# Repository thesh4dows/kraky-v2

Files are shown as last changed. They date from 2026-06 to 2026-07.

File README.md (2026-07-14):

# kraky-v2
Kraky2 is the second version of the DIY and open-hardware poject inspired by the Flipper Zero.
It uses the esp32-S3 microntroller to manage all the different modules like the NFC,RFID, and some.

The module is divided in 2 layers, the front one houses the esp32, Wifi and Sub-GHz antennas, buttons, IR and a part of the
power delivery system; the back one houses the NFC and RFID modules on top of the rest of the power delivery system.

Using the four buttons you can take advantage of all the modules that composes the kraky2, you can also use it connected to 
a battery or via the usb-c port that is integrated in the circuit.

I would suggest putting first the esp32 as is the most difficult part to put, then the others chip, all the capacitors, resistors, inductors and so on and for last all the
tht components because they are the ones that pass through the board so they are more simple to put.

I started this journey because i want to create a better version of my project kraky, and i'm doing it by first using smd components instead of the 
tht modules so i can do some expirience soldering very small parts and stopping using pre made modules but recreating them myself.
420.65
---

# Main Components
| Function | Component |
|---|---|
| Logic board | **ESP32-S3 N16R8** |
| wifi | **nrf24l01** |
| Sub-GHz | **CC1101** |
| RFID | **MFRC522** |
| NFC | **PN532** |
| Battery charger | **CN3163** |
| Battery | Li-ion |
| IR Receiver | **TSOP38238** |
| IR Transmitter | IR LED |
| microSD Slot | **MSD4A** |
| Buttons | 4 tactile buttons |
| Display | TFT Display |

---

# WIRING DIAGRAM

# ESP32



 # POWER DELIVERY SYSTEM
 


# IR



# WIFI



# SUB-GHZ



# MICROSD SLOT



# NFC



# RFID



# BUTTONS



# DISPLAY



---

# PCB



---

# 3D RENDER





---
# Responsible Use
Kraky2 is built to make it easier for anyone to explore and understand how multifunction electronic devices work in everyday life. It’s not intended for bypassing security systems or breaking any laws.

All features are implemented with an educational and experimental focus.

---

# Zine page

kraky2 poster (5)

---

# Tools Used

- KiCad 10
- Fusion360
- PlatformIO
---
## Contributing

Kraky is an **open and educational project**.  
Feedback, suggestions, and improvements are always welcome.

---

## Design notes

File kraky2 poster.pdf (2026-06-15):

# KRAKY2

## SUB-GHZ

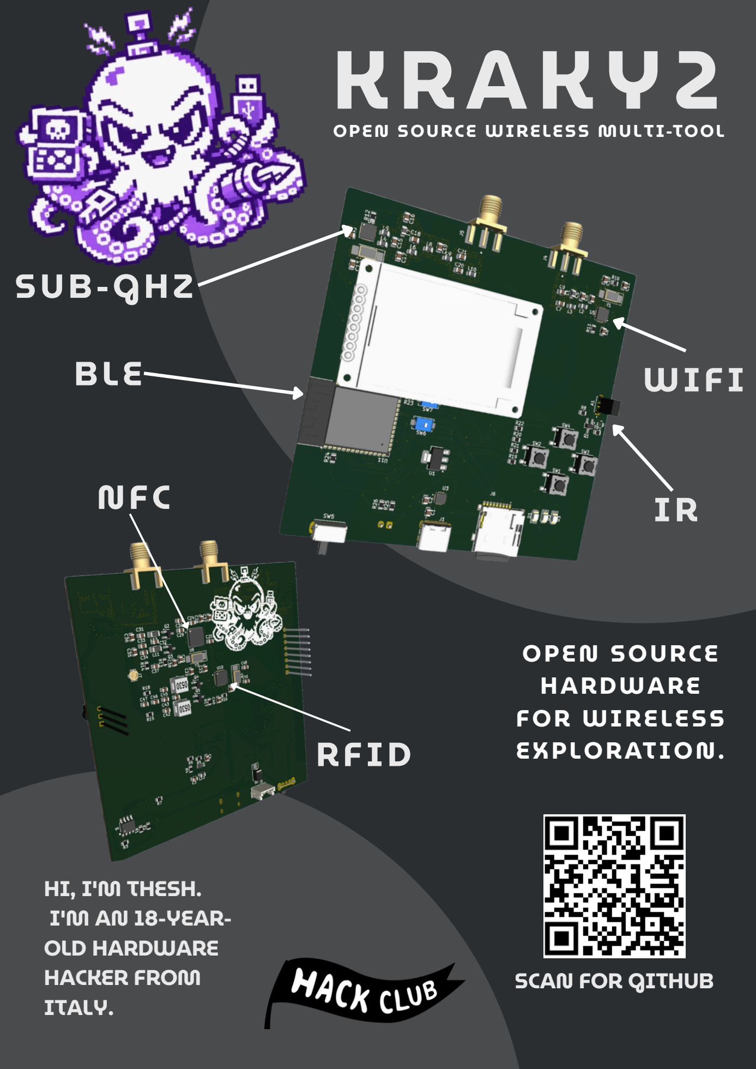
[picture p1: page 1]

HI, I'M THESH.
I'M AN 18-YEAR-OLD HARDWARE
HACKER FROM
ITALY.

SCAN FOR GITHUB

## NFC

## RFID

## WIFI

IR

## BLE

OPEN SOURCE WIRELESS MULTI-TOOL

OPEN SOURCE
HARDWARE
FOR WIRELESS
EXPLORATION.

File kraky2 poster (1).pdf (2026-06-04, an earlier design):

# KRAKY2

## SUB-GHZ

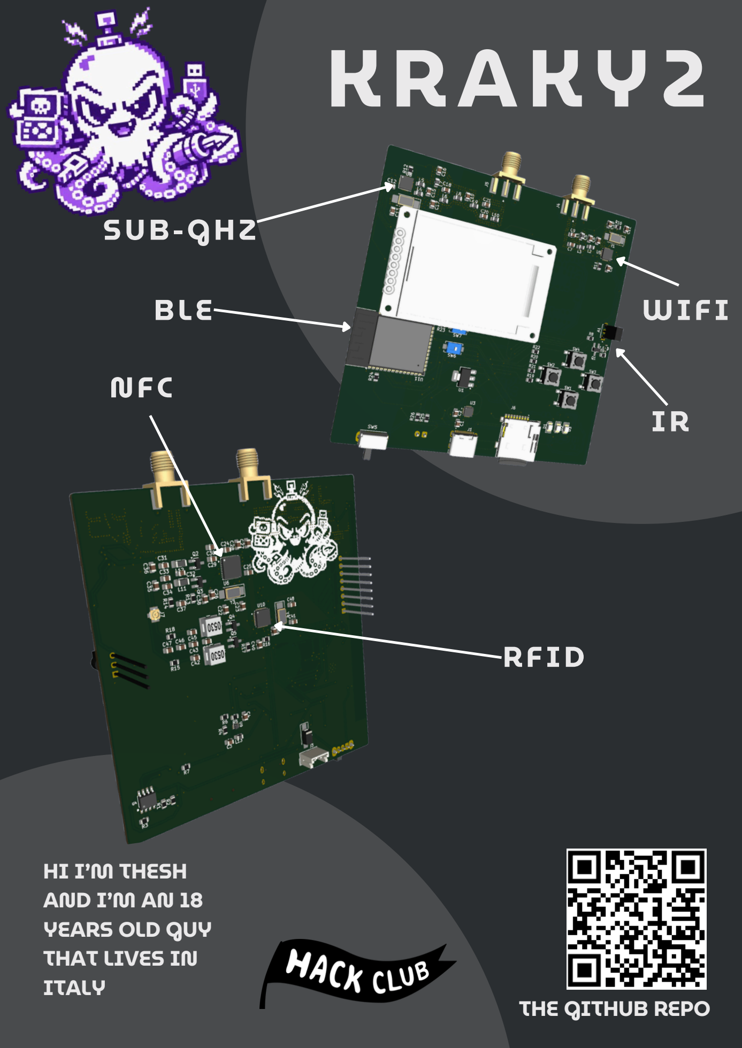
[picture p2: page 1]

HI I’M THESH
AND I’M AN 18
YEARS OLD GUY
THAT LIVES IN
ITALY
THE GITHUB REPO

## NFC

## RFID

## WIFI

IR

## BLE

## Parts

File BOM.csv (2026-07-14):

name | value | link | description | cost | quantity | added
resistor
R1 | 220 | https://it.aliexpress.com/item/1005010070793079.html?curPageLogUid=H7QIyXNC0fT4 | 805 | 1.45 | 3
R2 | 220 | R1 | 805 | R1 | R1
R3 | 3.6K | https://it.aliexpress.com/item/1005010070793079.html?curPageLogUid=H7QIyXNC0fT4 | 805 | 1.45 | 1
R4 | 100 | https://it.aliexpress.com/item/1005010070793079.html?curPageLogUid=H7QIyXNC0fT4 | 805 | 1.45 | 2
R5 | 732K | https://it.aliexpress.com/item/1005005184230104.html?curPageLogUid=FjpJxLWFyGgd | 805 | 2.07 | 1
R6 | 100K | https://it.aliexpress.com/item/1005010070793079.html?curPageLogUid=H7QIyXNC0fT4 | 805 | 1.45 | 3
R7 | 220 | R1 | 805 | R1 | R1
R8 | 1K | https://it.aliexpress.com/item/1005010070793079.html?curPageLogUid=H7QIyXNC0fT4 | 805 | 1.45 | 6
R9 | 100 | R4 | 805 | R4 | R4
R10 | 1M | https://it.aliexpress.com/item/1005010070793079.html?curPageLogUid=H7QIyXNC0fT4 | 805 | 1.46 | 1
R11 | 22K | https://it.aliexpress.com/item/1005010070793079.html?curPageLogUid=H7QIyXNC0fT4 | 805 | 1.45 | 1
R12 | 56K | https://it.aliexpress.com/item/1005010070793079.html?curPageLogUid=H7QIyXNC0fT4 | 805 | 1.45 | 1
R13 | 1K | R8 | 805 | R8 | R8
R14 | 1.6K | https://it.aliexpress.com/item/1005010070793079.html?curPageLogUid=H7QIyXNC0fT4 | 805 | 1.45 | 1
R15 | 1K | R8 | 805 | R8 | R8
R16 | 1K | R8 | 805 | R8 | R8
R17 | 1K | R8 | 805 | R8 | R8
R18 | 1K | R8 | 805 | R8 | R8
R19 | 10K | https://it.aliexpress.com/item/1005010070793079.html?curPageLogUid=H7QIyXNC0fT4 | 805 | 1.45 | 6
R20 | 10K | R19 | 805 | R19 | R19
R21 | 10K | R19 | 805 | R19 | R19
R22 | 10K | R19 | 805 | R19 | R19
R23 | 10K | R19 | 805 | R19 | R19
R24 | 10K | R19 | 805 | R19 | R19
R25 | 100K | R6 | 805 | R6 | R6
R26 | 100K | R6 | 805 | R6 | R6
capacitor
C1 | 0.1 uF | https://it.aliexpress.com/item/1005005929029743.html?curPageLogUid=6vnH26Bvr1Cc | 805 | 1.22 | 7
C2 | 1 uF | https://it.aliexpress.com/item/1005005929029743.html?curPageLogUid=6vnH26Bvr1Cc | 805 | 1.6 | 11
C3 | 10 uF | https://it.aliexpress.com/item/1005005929029743.html?curPageLogUid=6vnH26Bvr1Cc | 805 | 1.46 | 2
C4 | 22 uF | https://it.aliexpress.com/item/1005005929029743.html?curPageLogUid=6vnH26Bvr1Cc | 805 | 1.6 | 1
C5 | 2.2 nF | https://it.aliexpress.com/item/1005005929029743.html?curPageLogUid=6vnH26Bvr1Cc | 805 | 1.36 | 1
C6 | 4.7 pF | https://it.aliexpress.com/item/1005005929029743.html?curPageLogUid=6vnH26Bvr1Cc | 805 | 1.36 | 1
C7 | 1.5 pF | https://it.aliexpress.com/item/1005005929029743.html?curPageLogUid=6vnH26Bvr1Cc | 805 | 1.36 | 3
C8 | 33 nF | https://it.aliexpress.com/item/1005005929029743.html?curPageLogUid=6vnH26Bvr1Cc | 805 | 1.37 | 1
C9 | 1 pF | https://it.aliexpress.com/item/1005005929029743.html?curPageLogUid=6vnH26Bvr1Cc | 805 | 1.36 | 2
C10 | 22 pF | https://it.aliexpress.com/item/1005005929029743.html?curPageLogUid=6vnH26Bvr1Cc | 805 | 1.38 | 6
C11 | 22 pF | C10 | 805 | C10 | C10
C12 | 100 nF | https://it.aliexpress.com/item/1005005929029743.html?curPageLogUid=6vnH26Bvr1Cc | 805 | 1.21 | 1
C13 | 27 pF | https://it.aliexpress.com/item/1005005929029743.html?curPageLogUid=6vnH26Bvr1Cc | 805 | 1.38 | 2
C14 | 27 pF | C13 | 805 | C13 | C13
C15 | 1 pF | C9 | 805 | C9 | C9
C16 | 100 pF | https://it.aliexpress.com/item/1005005929029743.html?curPageLogUid=6vnH26Bvr1Cc | 805 | 1.36 | 1
C17 | 1.5 pF | C7 | 805 | C7 | C7
C18 | 1.5pF | C7 | 805 | C7 | C7
C19 | 3.3 pF | https://it.aliexpress.com/item/1005005929029743.html?curPageLogUid=6vnH26Bvr1Cc | 805 | 1.38 | 1
C20 | 47 pF | https://it.aliexpress.com/item/1005005929029743.html?curPageLogUid=6vnH26Bvr1Cc | 805 | 1.38 | 1
C21 | 12 pF | https://it.aliexpress.com/item/1005005929029743.html?curPageLogUid=6vnH26Bvr1Cc | 805 | 1.38 | 1
C22 | 22 pF | C10 | 805 | C10 | C10
C23 | 22 pF | C10 | 805 | C10 | C10
C24 | 0.1 uF | C1 | 805 | C1 | C1
C25 | 0.1 uF | C1 | 805 | C1 | C1
C26 | 0.1 uF | C1 | 805 | C1 | C1
C27 | 0.1 uF | C1 | 805 | C1 | C1
C28 | 10 uF | C3 | 805 | C3 | C3
C29 | 0.1 uF | C1 | 805 | C1 | C1
C30 | 4.7 uF | https://it.aliexpress.com/item/1005005929029743.html?curPageLogUid=6vnH26Bvr1Cc | 805 | 1.6 | 1
C31 | 22 pF | C10 | 805 | C10 | C10
C32 | 220 pF | https://it.aliexpress.com/item/1005005929029743.html?curPageLogUid=6vnH26Bvr1Cc | 805 | 1.38 | 2
C33 | 220 pF | C32 | 805 | C32 | C32
C34 | 22 pF | C10 | 805 | C10 | C10
C35 | 200 pF | https://it.aliexpress.com/item/1005005929029743.html?curPageLogUid=6vnH26Bvr1Cc | 805 | 1.38 | 2
C36 | 200 pF | C35 | 805 | C35 | C35
C37 | 1 nF | https://it.aliexpress.com/item/1005005929029743.html?curPageLogUid=6vnH26Bvr1Cc | 805 | 1.37 | 1
C38 | 0.1 uF | C1 | 805 | C1 | C1
C39 | 1 uF | C2 | 805 | C2 | C2
C40 | 1 uF | C2 | 805 | C2 | C2
C41 | 1 uF | C2 | 805 | C2 | C2
C42 | 1 uF | C2 | 805 | C2 | C2
C43 | 1 uF | C2 | 805 | C2 | C2
C44 | 1 uF | C2 | 805 | C2 | C2
C45 | 1 uF | C2 | 805 | C2 | C2
C46 | 1 uF | C2 | 805 | C2 | C2
C47 | 1 uF | C2 | 805 | C2 | C2
C48 | 1 uF | C2 | 805 | C2 | C2
inductor
L1 | 2.7 nH | https://it.aliexpress.com/item/1005003062755166.html?curPageLogUid=HGVAlLHM7vi2 | 805 | 1.65 | 1
L2 | 8.2 nH | https://it.aliexpress.com/item/1005003062755166.html?curPageLogUid=HGVAlLHM7vi2 | 805 | 1.62 | 1
L3 | 3.9 nH | https://it.aliexpress.com/item/1005003062755166.html?curPageLogUid=HGVAlLHM7vi2 | 805 | 1.62 | 1
L4 | 33 nH | https://it.aliexpress.com/item/1005006165931240.html?curPageLogUid=9K7uLeTzDaML | 805 | 5.47 | 2
L5 | 33 nH | L4 | 805 | L4 | L4
L6 | 18 nH | https://it.aliexpress.com/item/1005003062755166.html?curPageLogUid=HGVAlLHM7vi2 | 805 | 1.62 | 2
L7 | 18 nH | L6 | 805 | L6 | L6
L8 | 12 nH | https://it.aliexpress.com/item/1005003062755166.html?curPageLogUid=HGVAlLHM7vi2 | 805 | 1.65 | 2
L9 | 12 nH | L8 | 805 | L8 | L8
L10 | 3.3 nH | https://it.aliexpress.com/item/1005003062755166.html?curPageLogUid=HGVAlLHM7vi2 | 805 | 1.62 | 1
L11 | 560 nH | https://it.aliexpress.com/item/1005003091167117.html?curPageLogUid=mVv6AIsGG76P | 1210 | 1.99 | 2
L12 | 560 nH | L11 | 1210 | L11 | L11
L13 | 1 uH | https://it.aliexpress.com/item/1005003827404196.html?curPageLogUid=LllgTqEMFPfj | 805 | 3.89 | 1
L14 | 1 mH | https://it.aliexpress.com/item/4001191068539.html?curPageLogUid=IFhwrmJCxCWl | 805 | 1.6 | 2
L15 | 1 mH | L14 | 805 | L14 | L14
crystal
Y1 | 16 MHz | https://it.aliexpress.com/item/1005007210644647.html?curPageLogUid=bcvfZR4XvBPS | 5032 | 3.16 | 1
Y2 | 26 MHz | https://it.aliexpress.com/item/1005004711354176.html?curPageLogUid=sEWfQk2pigRD | 5032 | 2.79 | 1
Y3 | 27.12 MHz | https://it.aliexpress.com/item/1005004711354176.html?curPageLogUid=sEWfQk2pigRD | 5032 | 2.75 | 2
Y4 | 27.12MHz | Y3 | 5032 | Y3 | Y3
buttons
SW1 | navigation | https://it.aliexpress.com/item/1005006870284823.html?curPageLogUid=iBAjoDabdN8o | smd 6x6 mm | 1.69 | 4
SW2 | navigation | SW1 | smd 6x6 mm | SW1 | SW1
SW3 | navigation | SW1 | smd 6x6 mm | SW1 | SW1
SW4 | navigation | SW1 | smd 6x6 mm | SW1 | SW1
SW5 | on/off | https://it.aliexpress.com/item/1005004328667818.html?scm_id=1007.40050.354490.0&scm-url=1007.40050.354490.0 | tht 3 way switch | 2.72 | 1
SW6 | RESET | https://it.aliexpress.com/item/1005008404608815.html?curPageLogUid=beYw408Avuco | smd 6x3 mm | 2.35 | 2
SW7 | BOOT | SW6 | smd 6x3 mm |  | SW6
modules
U1 | AMS1117-3.3 | https://it.aliexpress.com/item/1005007027620474.html?curPageLogUid=eo6dvrBMm3cE | voltage regulator | 1.25 | 1
U2 | ESP32-S3-WROOM-1-N4R2 | https://it.aliexpress.com/item/1005006214506085.html | ESP32 S3 N16R8 | 4.99 | 1
U3 | CH343P | https://it.aliexpress.com/item/1005009691777003.html?curPageLogUid=lfFt8St0bZKK | com converter | 4.54 | 1
U4 | CN3063-SOIC8 | https://it.aliexpress.com/item/1005006908180461.html?curPageLogUid=8cHjriHsLvvB | battery protection | 2.43 | 1
U5 | NRF24L01 | https://it.aliexpress.com/item/1005008669394507.html?curPageLogUid=WSLfC61CjqIJ | wifi module | 6.02 | 1
U6 | PN5321A3HN_C1xx | https://it.aliexpress.com/item/1005012051748463.html?curPageLogUid=8bTBY4V21dm6 | nfc module | 6.6 | 1
ext | NFC_ANTENNA | https://it.aliexpress.com/item/1005007698497375.html?curPageLogUid=fSUOjAmIQe1a | nfc antenna | 8.53 | 1
U8 | CC1101 | https://it.aliexpress.com/item/1005007128993296.html?curPageLogUid=uCi7b2Ehsp0B | subG module | 1.89 | 1
U9 | TPS61023DRLR | https://it.aliexpress.com/item/1005009341066247.html?curPageLogUid=EW8RQjSW1YOl | voltage booster | 2.73 | 1
U10 | MFRC522 | https://it.aliexpress.com/item/1005006882991356.html?curPageLogUid=t0XBgZNRLswo | rfid chip | 5.62 | 1
leds
D1 | LED | https://it.aliexpress.com/item/32868897187.html?curPageLogUid=WrrkifD2CvJr | 1206 | 2.8 | 1
D2 | LED | https://it.aliexpress.com/item/1005007189026364.html?curPageLogUid=hpyrOKRV4CxG | 1206 | 1.55 | 1
D3 | LED | https://it.aliexpress.com/item/1005007189026364.html?curPageLogUid=hpyrOKRV4CxG | 1206 | 1.46 | 1
D4 | IRLED | https://it.aliexpress.com/item/1005010507118978.html?curPageLogUid=Z8oAhbBpiGvW | IR led | 4.89 | 1
transistors
Q1 | 2N3904 | https://it.aliexpress.com/item/1005006501709413.html?curPageLogUid=lXuedVDa8ppn | IR transistor | 1.17 | 1
Q2 | BC817 | https://it.aliexpress.com/item/1005006943124825.html?curPageLogUid=QT5Nw3KXJYIP | Antenna transistor | 1.17 | 4
Q3 | BC817 | Q2 | Antenna transistor | Q2 | Q2
Q4 | BC817 | Q2 | Antenna transistor | Q2 | Q2
Q5 | BC817 | Q2 | Antenna transistor | Q2 | Q2
diodes
D5 | 1N5817 | https://it.aliexpress.com/item/1005006884142108.html?curPageLogUid=pNE6jaPw82sV | smd | 1.69 | 1
others
A1 | TSOP38238 | https://it.aliexpress.com/item/1005008745425158.html?curPageLogUid=qJE8AEBCzdoq | IR reciver | 2.8 | 1
J1 | CQ-USB-C16PSMT01 | https://it.aliexpress.com/item/1005010643898257.html?curPageLogUid=aFt3XDvcOZhM | USB-C port | 2.27 | 1
J2 | PINHD_1x8_Female | https://it.aliexpress.com/item/1005009269759277.html?mp=1 | display | 3.08 | 1
J3 | JST_02 | https://it.aliexpress.com/item/1005009883885132.html | battery plug | 2.22 | 1
J4 | 142-0701-501 | https://it.aliexpress.com/item/1005009514982478.html?curPageLogUid=lCuaA8hYuMzd | antenna | 4.79 | 2
J5 | 142-0701-501 | J4 | antenna | J4 | J4
battery | li-on battery | https://it.aliexpress.com/item/1005009932615983.html?curPageLogUid=ReWIC8XHdLaH | inr18650 | 4.91 | 1
J6 | MSD-4-A | https://it.aliexpress.com/item/1005006273533788.html?scm_id=1007.40050.354490.0&scm-url=1007.40050.354490.0 | microsd port | 2.24 | 1
J7 | U.FL-R-SMT_01_ | https://it.aliexpress.com/item/1005005916203605.html?curPageLogUid=NtsohWME3dss | nfc antenna | 1.65 | 1
rf antennas | antennas | https://it.aliexpress.com/item/1005009456185238.html?curPageLogUid=LxZNGYLj3zpj | subg and wifi antennas | 2.67 | 2
pcb
pcb | pcb |  | the motherboard of the project | 76.76 | 1
stencil | stencil | pcb | to put the solder paste | pcb | pcb
tools
solder paste | paste | https://it.aliexpress.com/item/1005008590694612.html?curPageLogUid=S2Oe7UAJmCP7 | for the smd components | 3.45 | 1
solder spool | solder | https://it.aliexpress.com/item/1005012037824511.html?curPageLogUid=fqKpRQII2cfI | for the tht components | 13.59 | 1
solder tips |  | https://it.aliexpress.com/item/1005005911711168.html |  | 7.21 | 2
smt base |  | https://it.aliexpress.com/item/1005009845177014.html?curPageLogUid=jnxrD94yzC86 |  | 55.82 | 1

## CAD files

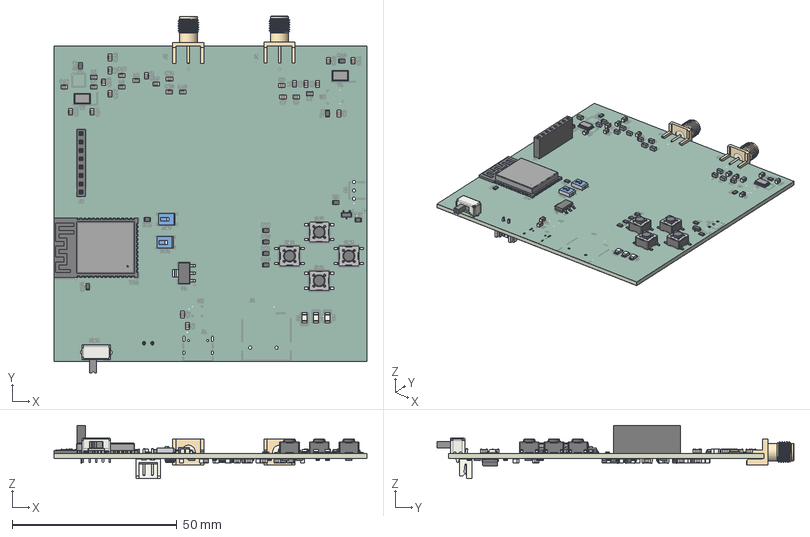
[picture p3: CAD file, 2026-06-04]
3D_RENDER/kraky2.step
95.0 x 108.2 x 16.2 mm
SMA_Molex_73251-1153_EdgeMount_Horizontal_1 x 2
R_0805_2012Metric_1 x 24
L_0805_2012Metric_1 x 15
SOT-23_1 x 5
PinSocket_1x08_P2.54mm_Vertical_1
ESP32-S3-WROOM-1_1
Crystal_SMD_5032-2Pin_5.0x3.2mm_1 x 4
SOT-223_1
C_0805_2012Metric_1 x 48
SW_SPST_EVQPE002 x 2
SW_SPST_EVQPE1_1 x 2
SW_SPST_PTS645Sx43SMTR92_1 x 4
SW_Slide_SPDT_Angled_CK_OS102011MA1Q_1
LED_1206_3216Metric_1 x 3
D_SMA_1
JST_B2B_EH_A
kraky2_silkscreen
kraky2_silkscreen_1
kraky2_soldermask
kraky2_soldermask_1
kraky2_PCB

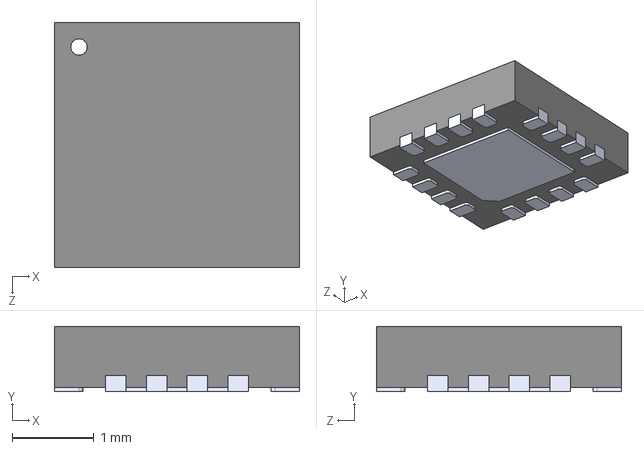
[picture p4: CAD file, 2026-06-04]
PCB/3D_renderes/CH343P--3DModel-STEP-418109.STEP
3.00 x 0.8 x 3.00 mm

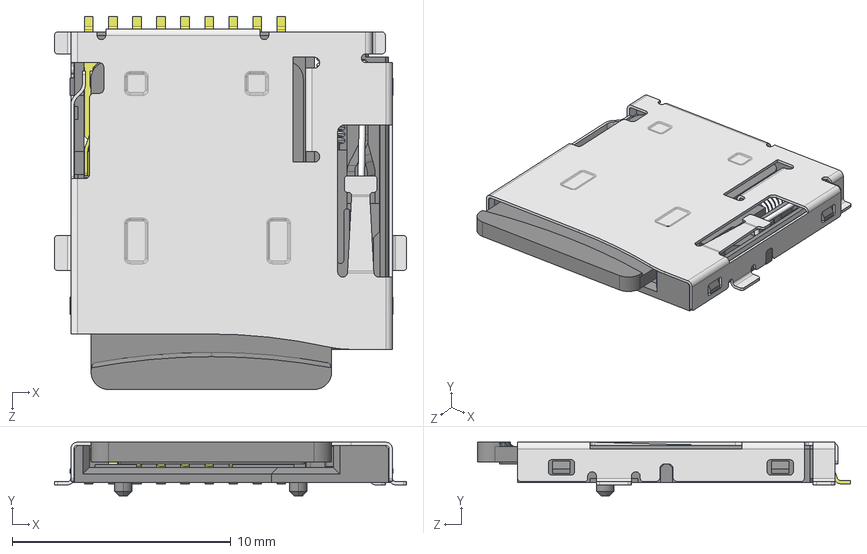
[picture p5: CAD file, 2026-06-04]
PCB/3D_renderes/MicroSD_Socket.STEP
16.1 x 2.45 x 17.0 mm
Case^MicroSD_Socket
Insert^MicroSD_Socket
Brace^MicroSD_Socket
Spring^MicroSD_Socket
Lid^MicroSD_Socket
Pin_Middle^MicroSD_Socket x 5
Pin_Short^MicroSD_Socket
Pin_Long^MicroSD_Socket x 2
MicroSD_Card^MicroSD_Socket
Pin_CardIn^MicroSD_Socket

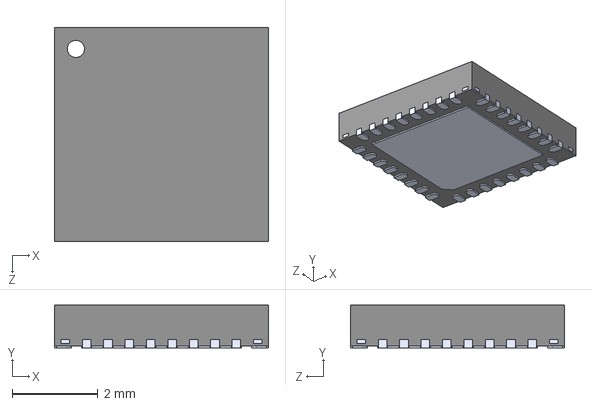
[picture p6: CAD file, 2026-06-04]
PCB/3D_renderes/MFRC52201HN1,115--3DModel-STEP-510211.STEP
5.00 x 1.00 x 5.00 mm

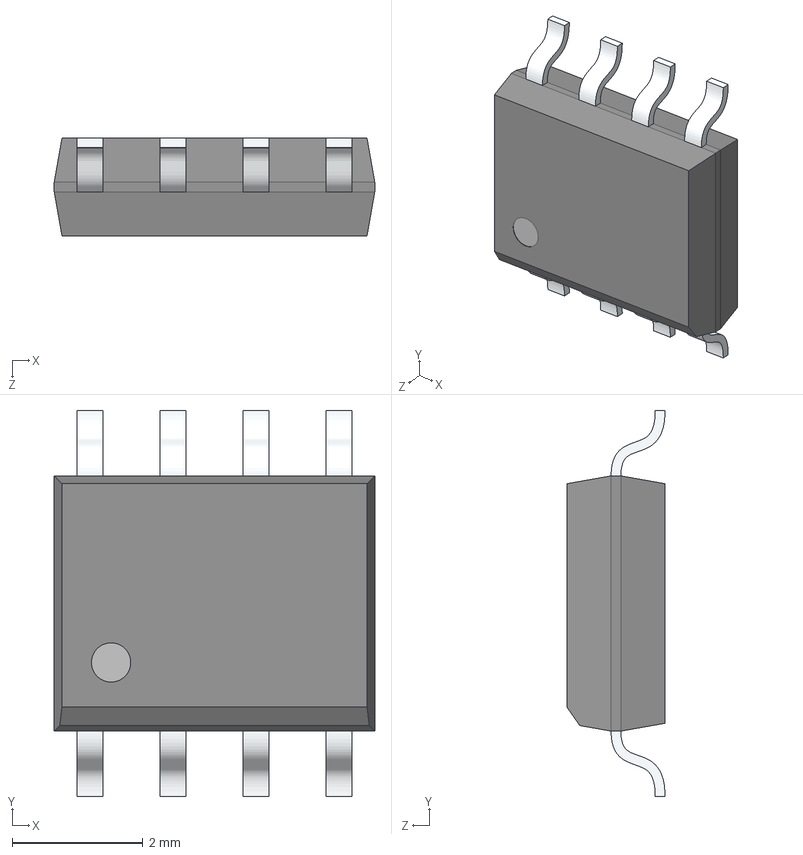
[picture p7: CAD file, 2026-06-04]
PCB/3D_renderes/SOIC8.STEP
4.90 x 5.90 x 1.50 mm

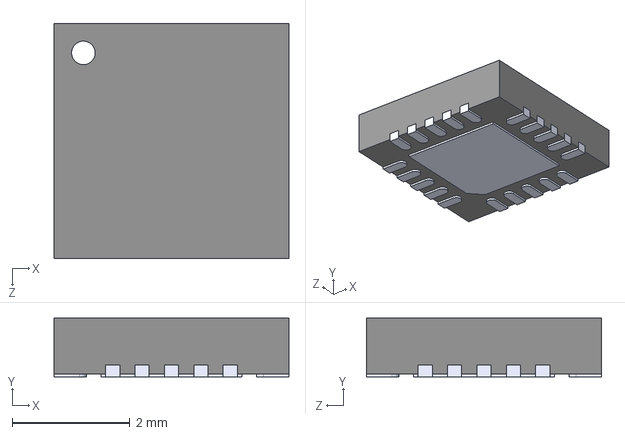
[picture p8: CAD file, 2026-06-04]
PCB/3D_renderes/CC1101RGP.STEP
4.00 x 1.00 x 4.00 mm

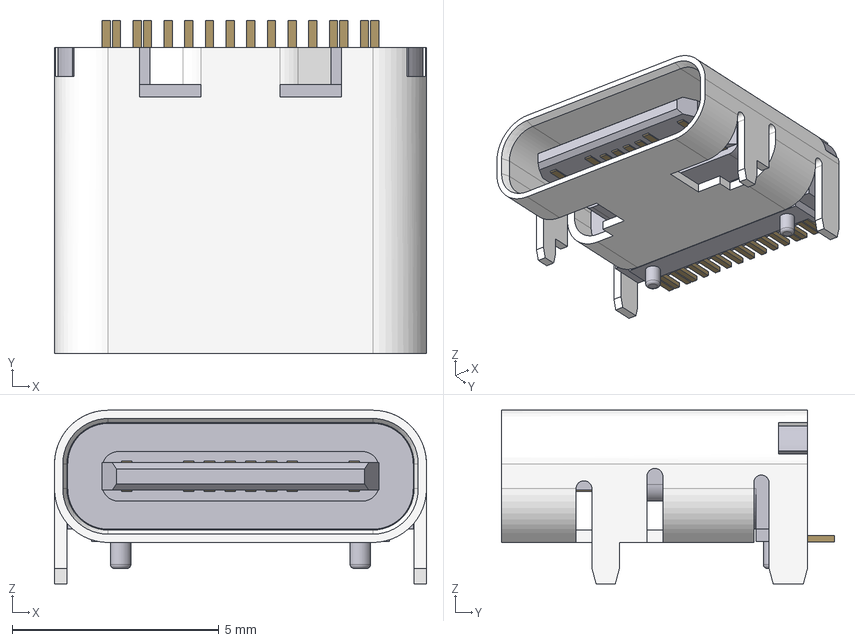
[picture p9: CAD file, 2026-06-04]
PCB/3D_renderes/usb-c_16pins_vertical.step
9.00 x 8.05 x 4.20 mm
tongue
shield
contact_001
contact_002
contact_003
contact_004
contact_court_001
contact_court_002
contact_court_003
contact_court_004
contact_005
contact_006
contact_007
contact_008
contact_court_005
contact_court_006
contact_court_007
contact_court_008
pin_001
pin_002
pin_003
pin_004
pin_005
pin_006
pin_007
pin_008
pin_009
pin_010
pin_011
pin_012
pin_013
pin_014
pin_015
pin_016

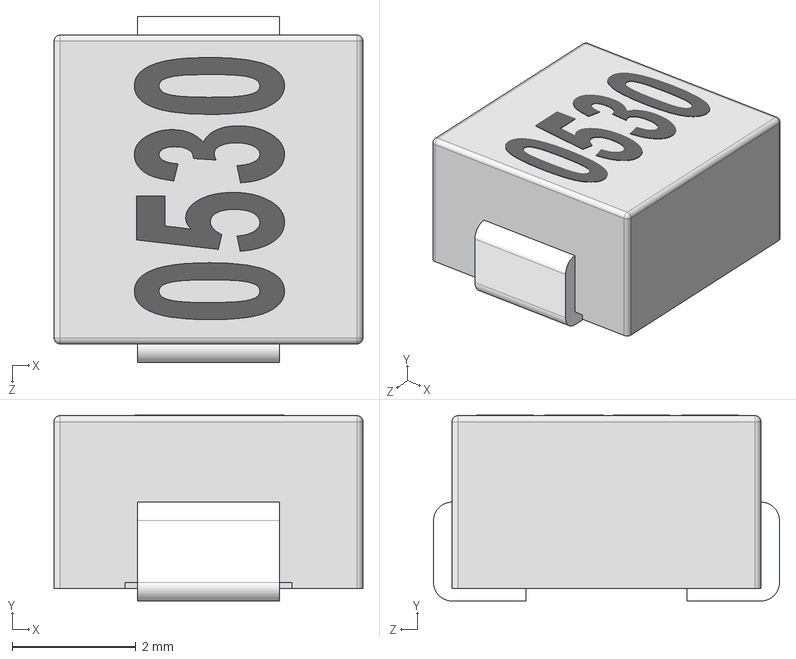
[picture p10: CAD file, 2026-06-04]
PCB/3D_renderes/Inductor_SMD_AMPLF_0530.STEP
5.00 x 3.01 x 5.60 mm

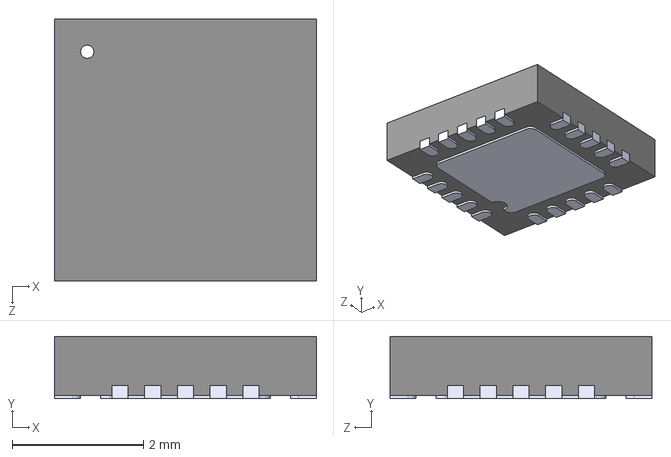
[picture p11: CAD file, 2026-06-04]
PCB/3D_renderes/NRF24L01--3DModel-STEP-56544.STEP
4.00 x 0.95 x 4.00 mm

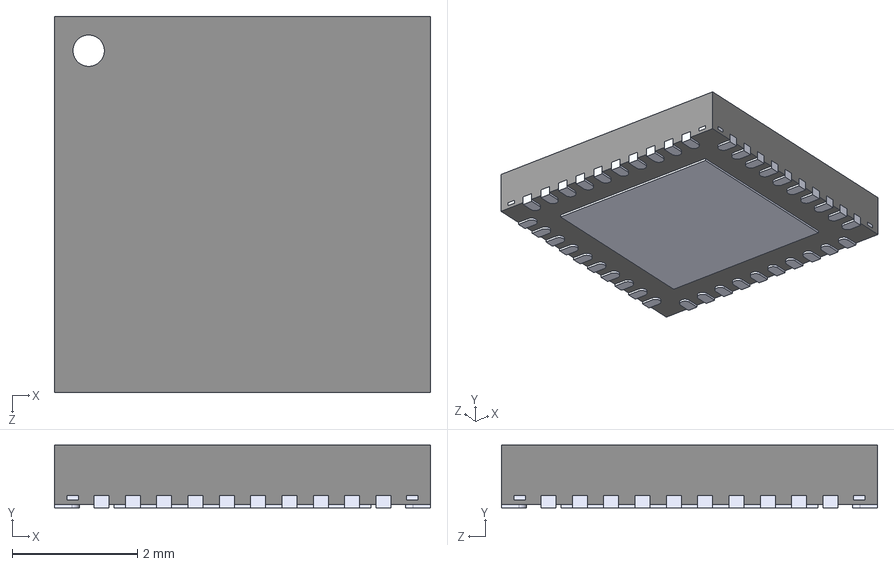
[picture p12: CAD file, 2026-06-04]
PCB/3D_renderes/PN5321A3HN_C106;55.STEP
6.00 x 1.00 x 6.00 mm

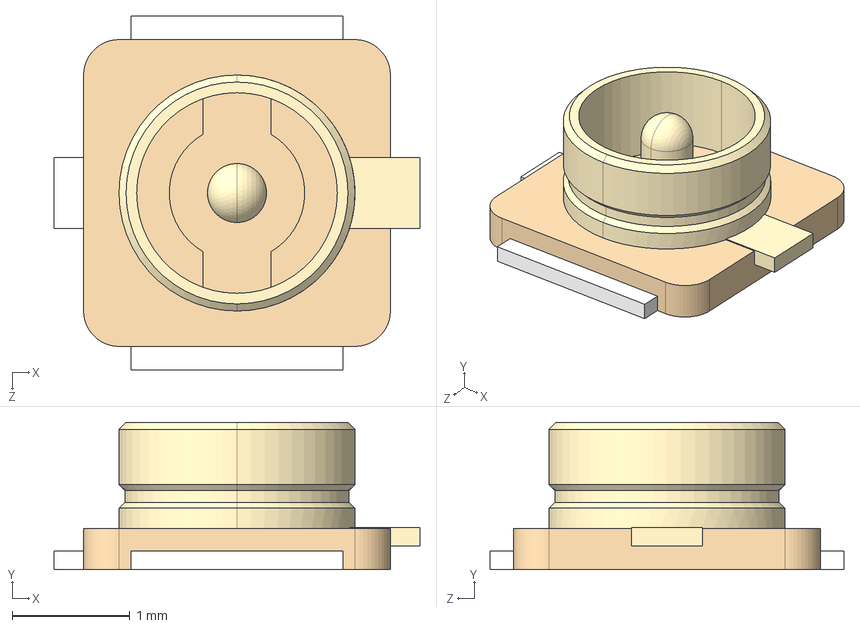
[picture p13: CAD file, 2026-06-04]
PCB/3D_renderes/U.FL-R-SMT(10)--3DModel-STEP-56544.STEP
3.10 x 1.25 x 3.00 mm

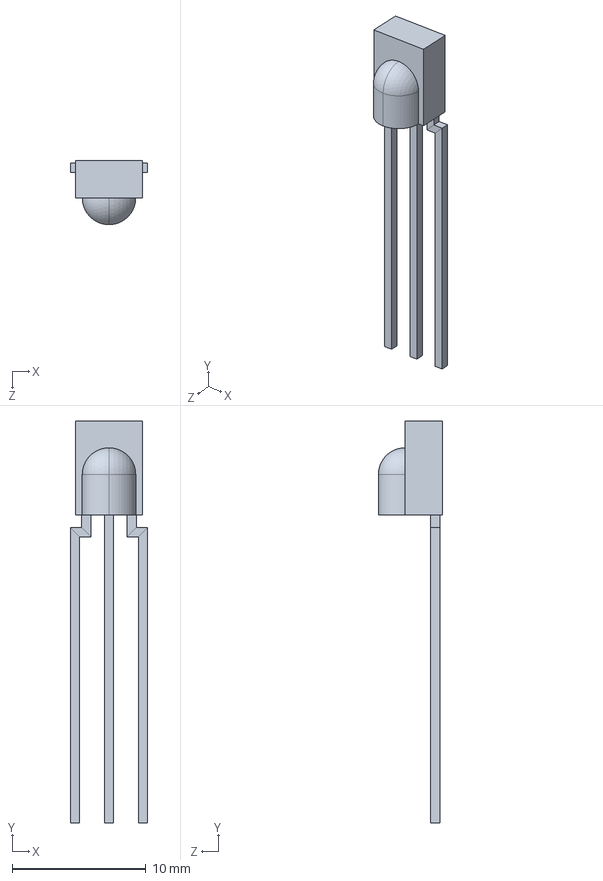
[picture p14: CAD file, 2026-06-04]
PCB/3D_renderes/IR Receiver.STEP
5.78 x 30.0 x 4.80 mm

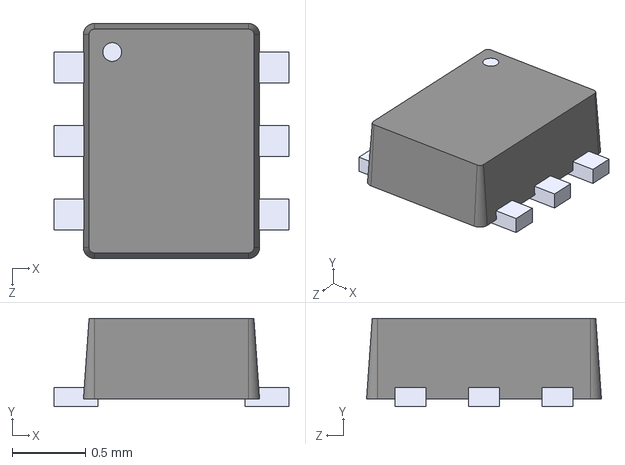
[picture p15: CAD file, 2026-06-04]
PCB/3D_renderes/TPS61023DRLR.STEP
1.60 x 0.6 x 1.60 mm

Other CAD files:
PCB/3D_renderes/birNoktaSekizInchTFTEkran.stp
3D_RENDER/kraky2.3mf
3D_RENDER/kraky2.f3d

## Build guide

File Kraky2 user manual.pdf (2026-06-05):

# Kraky2 user manual

This is kraky2, a pentesting tool that is designed to analyze a lot of different radio frequencies, like wifi, bluetooth, sub-GHz and many more.

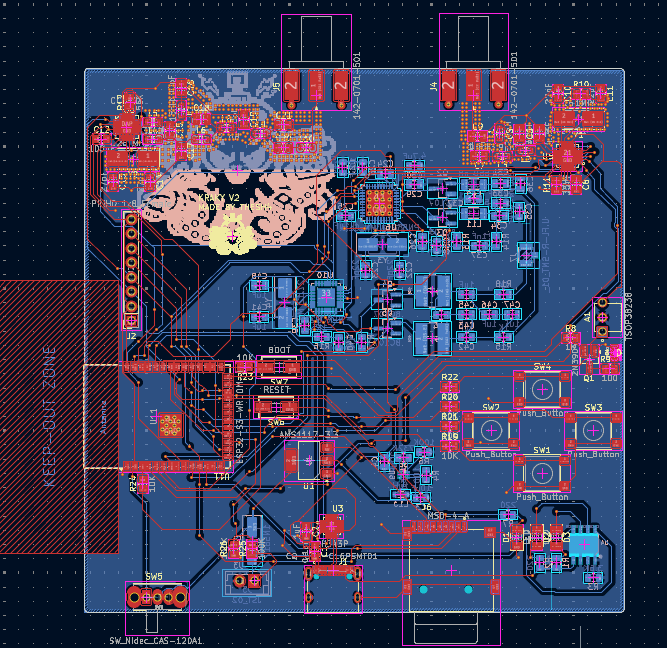
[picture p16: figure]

# ESP32-S3

We have chosen the ESP32-S3 for the brain of this tool, because of his great capabilities and the possibility to introduce AI in this project later.
The ESP32-S3 handles all the communications between the modules, keeps the firmware and is responsible for the functionalities of the bluetooth.
Near the ESP32-S3 there are two buttons that have the function of boot and reset, so the it can be programmable.

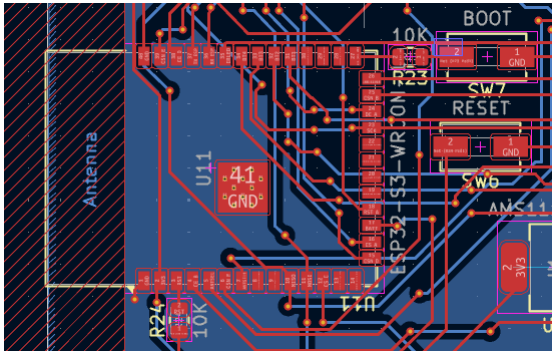
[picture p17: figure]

# Sub-GHz

The sub-GHz function is handled by the CC1101 chip that is built to do 819MHz, this chip is one of the most capable in the sub-GHz category and is very convenient because it uses SPI, which if you have a lot of modules comes in very handy.
We built the antenna so it can have very little interference on the 819 MHz range, to build it we referenced the CC1101 manual.
The CC1101 is connected to the ESP32 with all the required wires for SPI and the CSN pin is connected to the GPIO pin number 3, and the CE pin is connected to the GPIO pin number 2.

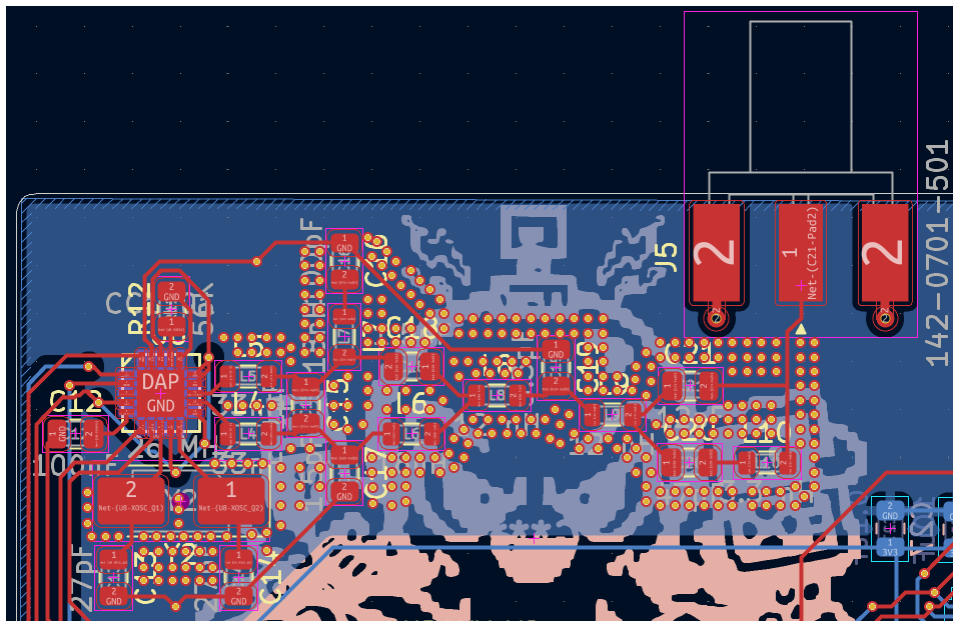
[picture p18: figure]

# WIFI

The wifi function is handled by the NRF24L01 chip that is built to scan and monitor all the wifi signals that are in range, it is also connected via SPI.
We, like the CC1101, used the NRF24L01 manual to build the antenna.
The NRF24L01 is connected to the ESP32 with all the required wires for SPI and the CSN pin is connected to the GPIO pin number 48, and the CE pin is connected to the GPIO pin number 4.

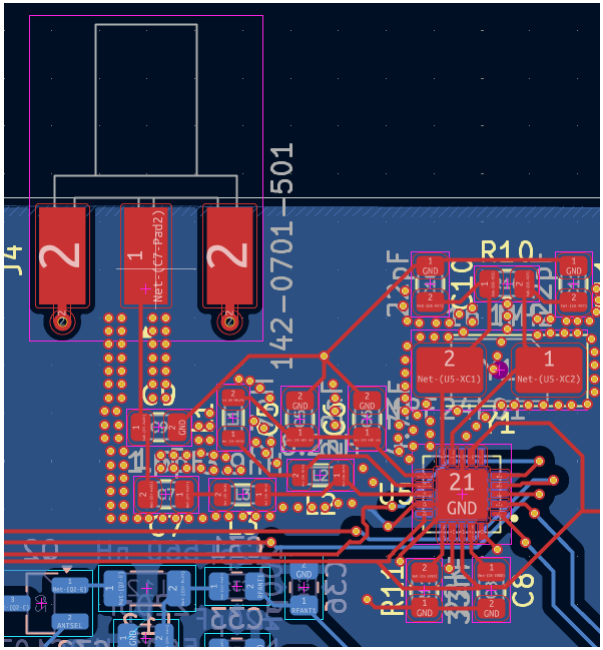
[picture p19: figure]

# NFC

the NFC module is the PN532 and is situated on the other side of the board and serves the function of reading and writing on NFC tag, at the moment the only thing that can write are hello NFC and something custom that we will write but hopefully in the future you can write what you want on the NFC tags.
The PN532 is also connected in SPI and the CSN is the GPIO pin number 1.
The NFC and RFID modules are connected together on the same antenna so there are 2 pairs of transistors that the NFC one is connected to the GPIO pin number 5.

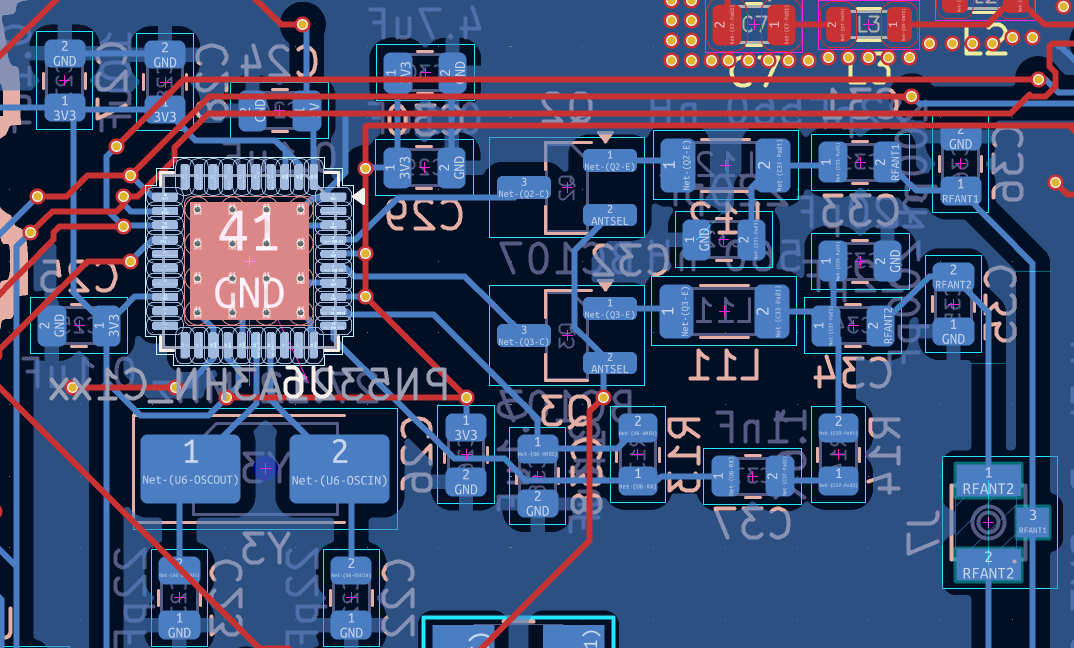
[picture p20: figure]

# RFID

The RFID module uses the MFRC522 chip and like the NFC module is situated on the other side of the board, for the development of the firmware we are a bit stuck because we don’t own any MFRC522 modules or chips so we can’t develop it at the moment.
The MFRC522 is connected with SPI and the CSN is the GPIO pin number 6, and the antenna selection pin is the GPIO pin number 7.

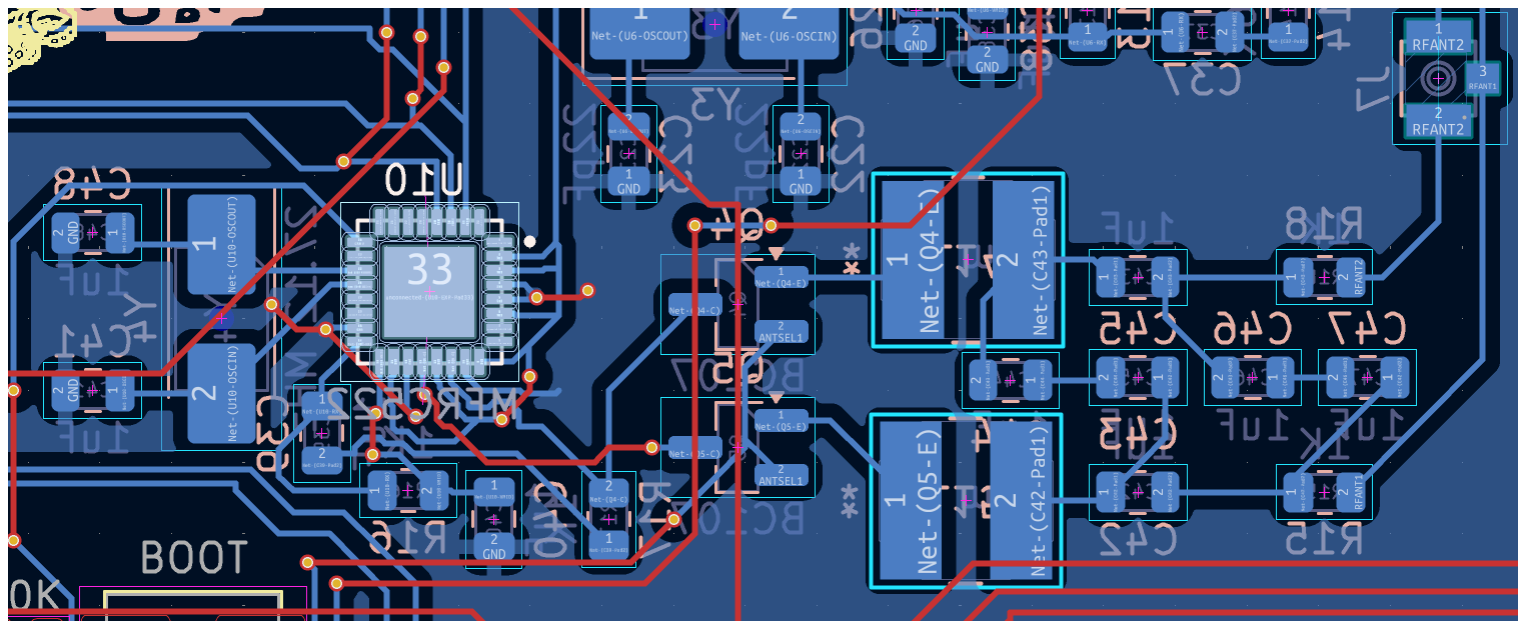
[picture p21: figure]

IR

The IR module is composed of an IR led connected to 2 resistors and a transistor so that the current that flows through it is limited, and a TSOP38238 that receives the IR waves and reads them.
The IR firmware is a bit complicated mainly because we don't have many things that we can try it on so it is a bit untested at the moment.
The IR led is connected to the ESP32 by the GPIO pin number 42, and the TSOP38238 is connected with the GPIO pin number 45.

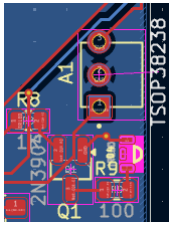
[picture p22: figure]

# Micro SD Slot

The micro SD slot was designed for a microSD card so with all the data that you have found you can store them in something much larger that the flash memory of the ESP32.
The micro SD slot is connected via SPI and the CSN pin is connected to the GPIO pin number 8.

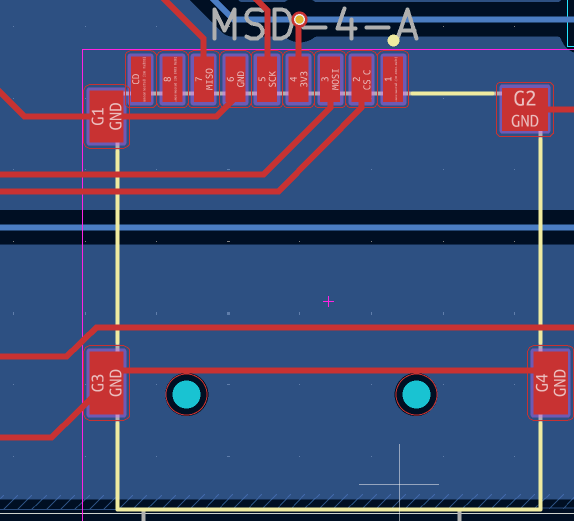
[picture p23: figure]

# Power delivery system

The power delivery and data delivery system is divided into 3 parts.
The first part is where the electricity enters, there are the USB-C port, the COM converter the CH343P, the ON/OFF switch, the battery connector, a diode so the current can enter the battery only by the battery charger, that is in the second part, 2 resistors that with some code can determine the charge of the battery, and last but not least the AMS1117-3.3 that converts the current from 5 volts into 3.3 volts.
In the second part there is the battery charger and protector of the CN3063 that help keep the battery healthy, and there are also the leds that tell you the state of the system, from active to charging to finished charging.
The third part has the TPS61023DRLR that converts the current from 3.3 volts into 5 volts when the Kraky2 is on battery mode, so there isn’t any 5 volt current in the system.

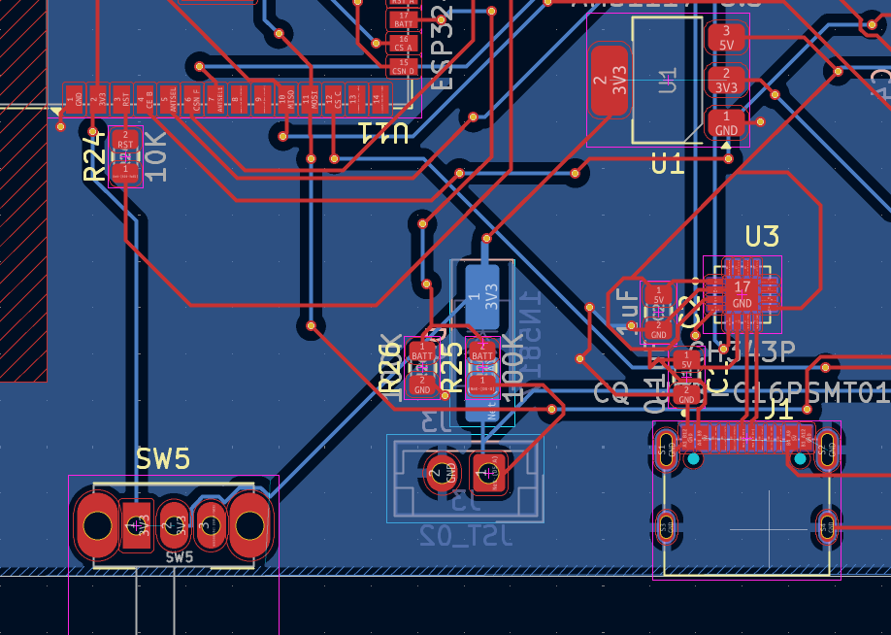
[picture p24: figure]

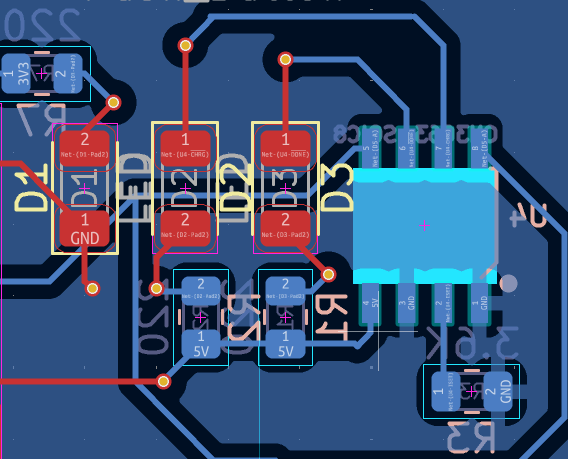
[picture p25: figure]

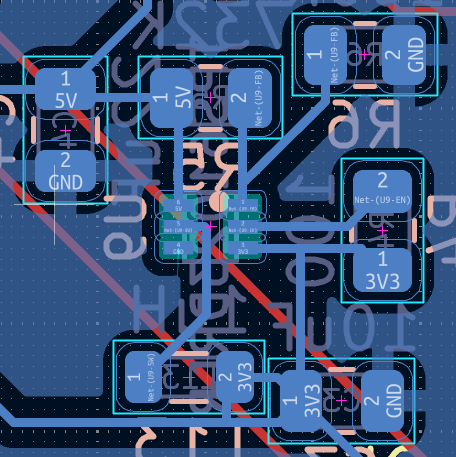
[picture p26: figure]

# Navigation buttons

The buttons serve the function of navigating the firmware that we have created, they divide in UP, the switch 4, DOWN, the switch 1, OK, the switch 3, and BACK, the switch 2.
Each of the switches are connected to the ESP32, the switch 4 is connected to the GPIO pin number 41, the switch 1 is connected to the GPIO pin number 38, the switch 3 is connected to the GPIO pin number 40 and the switch 2 is connected to the GPIO pin number 39.
They are each connected to a 10K Ω pull-up resistor so the signal can be more clean.

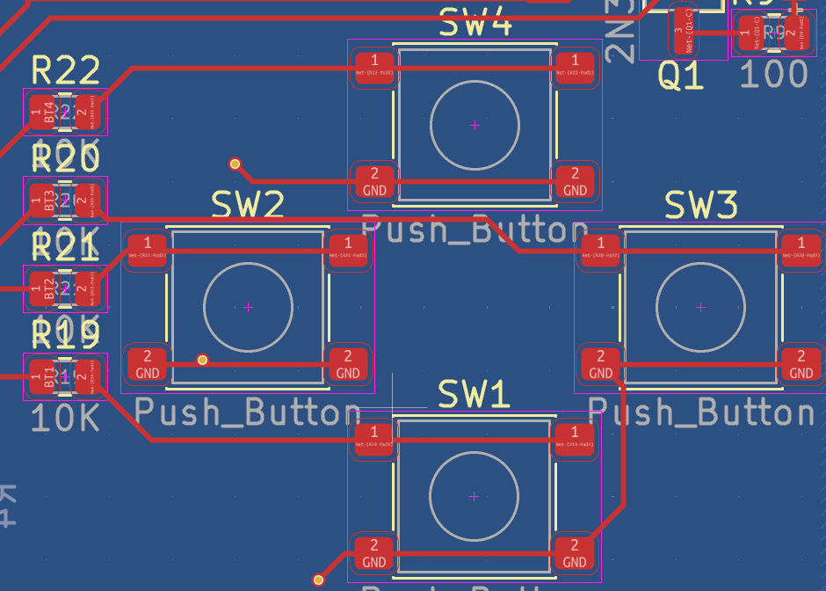
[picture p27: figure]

# The display

The display is a tft 1.8” 128*160 display, with the driver ST7735ST.
The display is connected to the ESP32 via SPI, and his CSN is the GPIO pin number 46, the DC is the GPIO pin number 47, and his RST is the GPIO pin number 10.

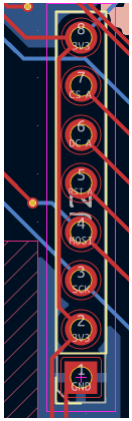
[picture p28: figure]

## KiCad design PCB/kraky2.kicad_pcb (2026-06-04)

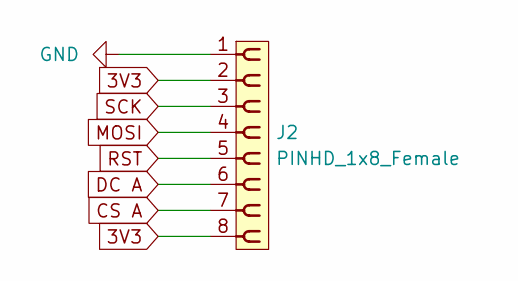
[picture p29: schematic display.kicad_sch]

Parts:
J2: PINHD_1x8_Female; PinSocket_1x08_P2.54mm_Vertical

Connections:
3V3: J2.2, J2.8; also elsewhere on the board
CS A: J2.7; also elsewhere on the board
DC A: J2.6; also elsewhere on the board
GND: J2.1; also elsewhere on the board
MOSI: J2.4; also elsewhere on the board
RST A: J2.5; also elsewhere on the board
SCK: J2.3; also elsewhere on the board

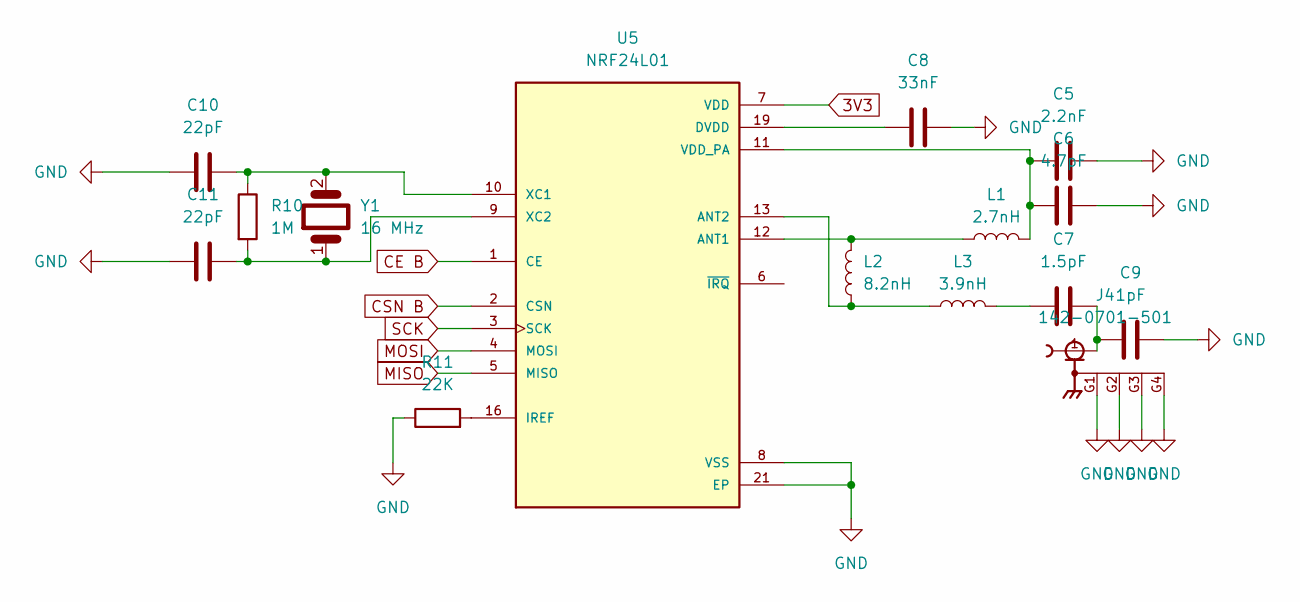
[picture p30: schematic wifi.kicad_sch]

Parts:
C5: 2.2nF; C_0805_2012Metric
C6: 4.7pF; C_0805_2012Metric
C7: 1.5pF; C_0805_2012Metric
C8: 33nF; C_0805_2012Metric
C9: 1pF; C_0805_2012Metric
C10, C11: 22pF; C_0805_2012Metric
J4: 142-0701-501; SMA_Molex_73251-1153_EdgeMount_Horizontal; PARTREV 7c
L1: 2.7nH; L_0805_2012Metric
L2: 8.2nH; L_0805_2012Metric
L3: 3.9nH; L_0805_2012Metric
R10: 1M; R_0805_2012Metric
R11: 22K; R_0805_2012Metric
U5: NRF24L01; QFN50P400X400X95-21N; PARTREV 2.0
Y1: 16 MHz; Crystal_SMD_5032-2Pin_5.0x3.2mm_HandSoldering

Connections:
3V3: U5.7 (VDD), U5.15 (VDD), U5.18 (VDD); also elsewhere on the board
CE B: U5.1 (CE); also elsewhere on the board
CSN B: U5.2 (CSN); also elsewhere on the board
GND: C5.2, C6.2, C8.2, C9.2, C10.1, C11.1, J4.G1, J4.G2, J4.G3, J4.G4, R11.1, U5.8 (VSS), U5.14 (VSS), U5.17 (VSS), U5.20 (VSS), U5.21 (EP); also elsewhere on the board
MISO: U5.5 (MISO); also elsewhere on the board
MOSI: U5.4 (MOSI); also elsewhere on the board
unnamed: C7.1, L3.2
unnamed: C7.2, C9.1, J4.1
unnamed: L1.1, L2.2, U5.12 (ANT1)
unnamed: L2.1, L3.1, U5.13 (ANT2)
unnamed: C8.1, U5.19 (DVDD)
unnamed: R11.2, U5.16 (IREF)
unnamed: C5.1, C6.1, L1.2, U5.11 (VDD_PA)
unnamed: C10.2, R10.1, U5.10 (XC1), Y1.2
unnamed: C11.2, R10.2, U5.9 (XC2), Y1.1
SCK: U5.3 (SCK); also elsewhere on the board

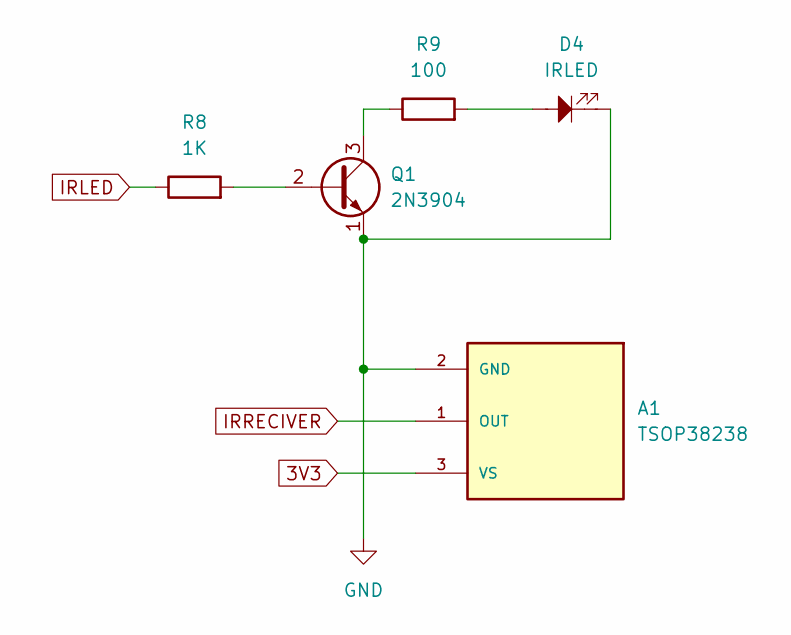
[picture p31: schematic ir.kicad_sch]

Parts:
A1: TSOP38238; XDCR_TSOP38238; PARTREV 1.7
D4: IRLED; WL-SISW_1002_15410294AA570
Q1: 2N3904; SOT-23_Handsoldering
R8: 1K; R_0805_2012Metric
R9: 100; R_0805_2012Metric

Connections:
3V3: A1.3 (VS); also elsewhere on the board
GND: A1.2 (GND), D4.1, Q1.1 (E); also elsewhere on the board
IRLED: R8.1; also elsewhere on the board
IRRECIVER: A1.1 (OUT); also elsewhere on the board
unnamed: D4.2, R9.2
unnamed: Q1.2 (B), R8.2
unnamed: Q1.3 (C), R9.1

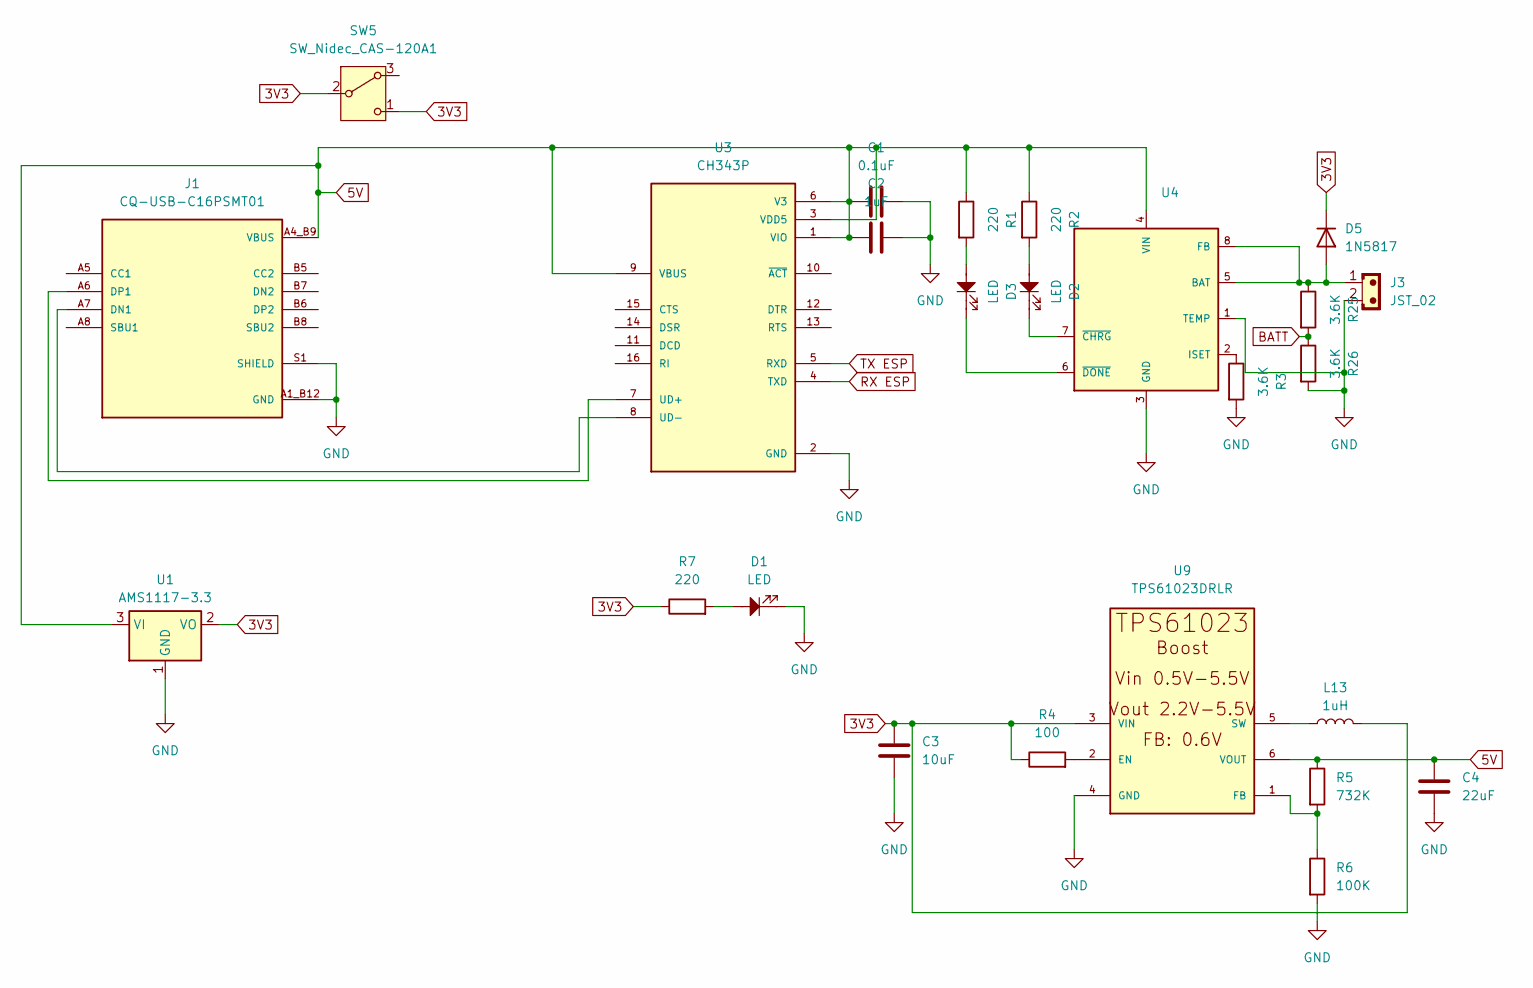
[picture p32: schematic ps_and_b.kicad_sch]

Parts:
C1: 0.1uF; C_0805_2012Metric
C2: 1uF; C_0805_2012Metric
C3: 10uF; C_0805_2012Metric
C4: 22uF; C_0805_2012Metric
D1, D2, D3: LED; LED_1206_3216Metric
D5: 1N5817; D_SMA_Handsoldering
J1: CQ-USB-C16PSMT01; SHENZHEN-CHUANGQIN-TECHNOLOGY_CQ-USB-C16PSMT01; PARTREV A
J3: JST_02; JST_EH_B2B-EH-A_1x02_P2.50mm_Vertical
L13: 1uH; L_0805_2012Metric
R1, R2, R7: 220; R_0805_2012Metric
R3, R25, R26: 3.6K; R_0805_2012Metric
R4: 100; R_0805_2012Metric
R5: 732K; R_0805_2012Metric
R6: 100K; R_0805_2012Metric
SW5: SW_Nidec_CAS-120A1; SW_Slide_SPDT_Angled_CK_OS102011MA1Q
U1: AMS1117-3.3; SOT-223-3_TabPin2
U3: CH343P; QFN50P300X300X80-17N; PARTREV 1E
U4: CN3063-SOIC8; SOIC8-1.27-5X4MM; MPN CN3063
U9: TPS61023DRLR; SOT563-ORI

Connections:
3V3: C3.1, D5.1 (K), L13.2, R4.1, R7.1, SW5.1 (C), SW5.2 (B), U1.2 (VO), U9.3 (VIN); also elsewhere on the board
5V: C1.1, C2.1, C4.1, J1.A4_B9 (VBUS), J1.B4_A9 (VBUS), R1.1, R2.1, R5.1, U1.3 (VI), U3.1 (VIO), U3.3 (VDD5), U3.6 (V3), U3.9 (VBUS), U4.4 (VIN), U9.6 (VOUT); also elsewhere on the board
BATT: R25.2, R26.1; also elsewhere on the board
GND: C1.2, C2.2, C3.2, C4.2, D1.1, J1.A1_B12 (GND), J1.B1_A12 (GND), J1.S1 (SHIELD), J1.S2 (SHIELD), J1.S3 (SHIELD), J1.S4 (SHIELD), J3.2, R3.2, R6.2, R26.2, U1.1 (GND), U3.2 (GND), U3.17 (GND), U4.1 (TEMP), U4.3 (GND), U9.4 (GND); also elsewhere on the board
unnamed: D1.2, R7.2
unnamed: D2.2, R2.2
unnamed: D3.2, R1.2
unnamed: D5.2 (A), J3.1, R25.1, U4.5 (BAT), U4.8 (FB)
unnamed: J1.A7 (DN1), U3.8 (UD-)
unnamed: J1.A6 (DP1), U3.7 (UD+)
unnamed: R3.1, U4.2 (ISET)
unnamed: D2.1, U4.7 (~CHRG)
unnamed: D3.1, U4.6 (~DONE)
unnamed: R4.2, U9.2 (EN)
unnamed: R5.2, R6.1, U9.1 (FB)
unnamed: L13.1, U9.5 (SW)
RX ESP: U3.4 (TXD); also elsewhere on the board
TX ESP: U3.5 (RXD); also elsewhere on the board

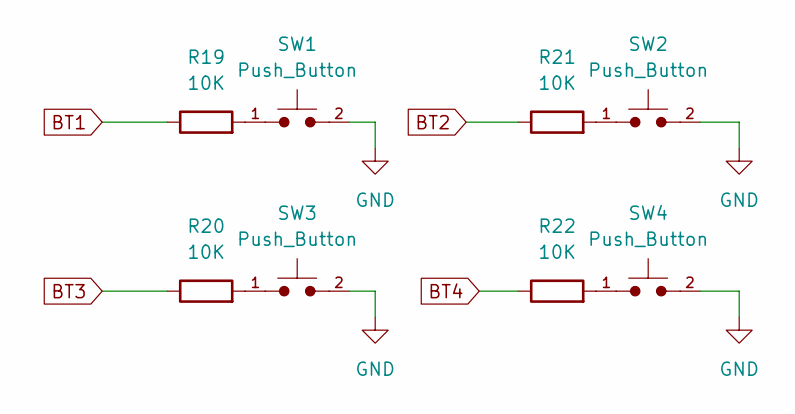
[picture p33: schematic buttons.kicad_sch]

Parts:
R19, R20, R21, R22: 10K; R_0805_2012Metric
SW1, SW2, SW3, SW4: Push_Button; SW_SPST_PTS645Sx43SMTR92

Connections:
BT1: R19.1; also elsewhere on the board
BT2: R21.1; also elsewhere on the board
BT3: R20.1; also elsewhere on the board
BT4: R22.1; also elsewhere on the board
GND: SW1.2, SW2.2, SW3.2, SW4.2; also elsewhere on the board
unnamed: R19.2, SW1.1
unnamed: R20.2, SW3.1
unnamed: R21.2, SW2.1
unnamed: R22.2, SW4.1

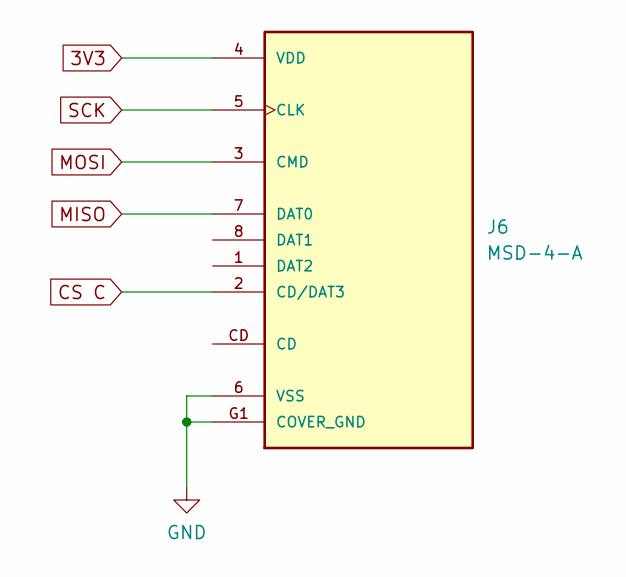
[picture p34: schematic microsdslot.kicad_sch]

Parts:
J6: MSD-4-A; CUI_MSD-4-A; PARTREV 1.0

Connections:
3V3: J6.4 (VDD); also elsewhere on the board
CS C: J6.2 (CD/DAT3); also elsewhere on the board
GND: J6.6 (VSS), J6.G1 (COVER_GND), J6.G2 (COVER_GND), J6.G3 (COVER_GND), J6.G4 (COVER_GND); also elsewhere on the board
MISO: J6.7 (DAT0); also elsewhere on the board
MOSI: J6.3 (CMD); also elsewhere on the board
SCK: J6.5 (CLK); also elsewhere on the board

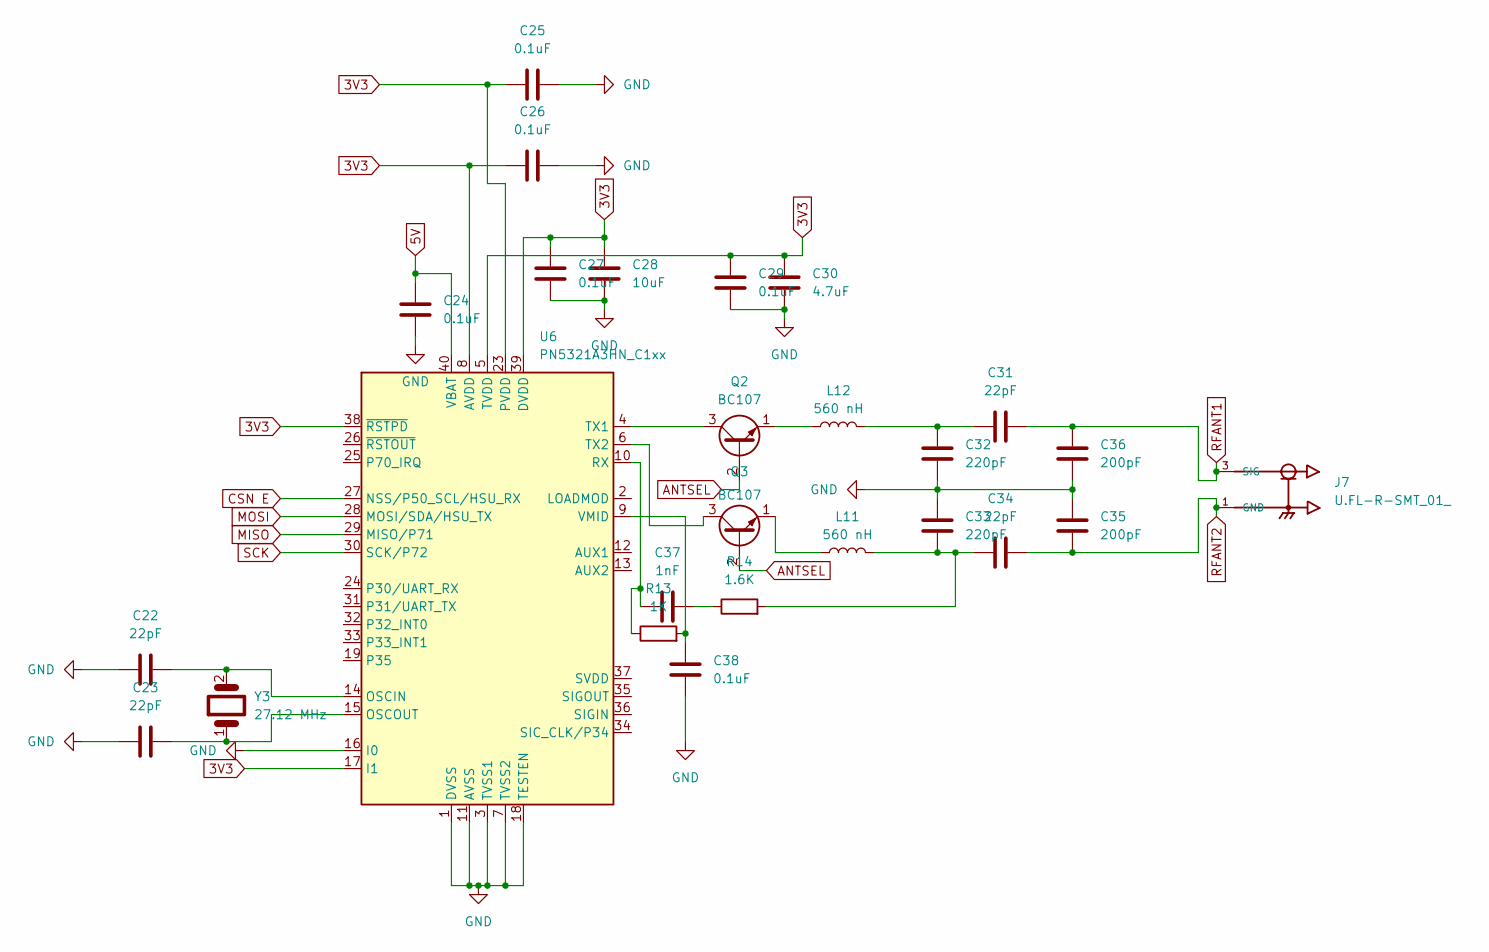
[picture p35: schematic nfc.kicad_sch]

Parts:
C22, C23, C31, C34: 22pF; C_0805_2012Metric
C24, C25, C26, C27, C29, C38: 0.1uF; C_0805_2012Metric
C28: 10uF; C_0805_2012Metric
C30: 4.7uF; C_0805_2012Metric
C32, C33: 220pF; C_0805_2012Metric
C35, C36: 200pF; C_0805_2012Metric
C37: 1nF; C_0805_2012Metric
J7: U.FL-R-SMT_01_; HRS_U.FL-R-SMT_01_
L11, L12: 560 nH; L_0805_2012Metric
Q2, Q3: BC107; SOT-23_Handsoldering
R13: 1K; R_0805_2012Metric
R14: 1.6K; R_0805_2012Metric
U6: PN5321A3HN_C1xx; HVQFN-40-1EP_6x6mm_P0.5mm_EP4.1x4.1mm_ThermalVias
Y3: 27.12 MHz; Crystal_SMD_5032-2Pin_5.0x3.2mm_HandSoldering

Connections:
3V3: C25.1, C26.1, C27.1, C28.1, C29.1, C30.1, U6.5 (TVDD), U6.8 (AVDD), U6.17 (I1), U6.23 (PVDD), U6.38 (~RSTPD), U6.39 (DVDD); also elsewhere on the board
5V: C24.1, U6.40 (VBAT); also elsewhere on the board
ANTSEL: Q2.2 (B), Q3.2 (B); also elsewhere on the board
CSN E: U6.27 (NSS/P50_SCL/HSU_RX); also elsewhere on the board
GND: C22.1, C23.1, C24.2, C25.2, C26.2, C27.2, C28.2, C29.2, C30.2, C32.1, C33.2, C35.1, C36.2, C38.2, U6.1 (DVSS), U6.3 (TVSS1), U6.7 (TVSS2), U6.11 (AVSS), U6.16 (I0), U6.18 (TESTEN), U6.41 (AVSS); also elsewhere on the board
MISO: U6.29 (MISO/P71); also elsewhere on the board
MOSI: U6.28 (MOSI/SDA/HSU_TX); also elsewhere on the board
unnamed: C31.1, C32.2, L12.2
unnamed: C33.1, C34.1, L11.2, R14.2
unnamed: C37.2, R14.1
unnamed: Q2.3 (C), U6.4 (TX1)
unnamed: L12.1, Q2.1 (E)
unnamed: Q3.3 (C), U6.6 (TX2)
unnamed: L11.1, Q3.1 (E)
unnamed: C22.2, U6.14 (OSCIN), Y3.2
unnamed: C23.2, U6.15 (OSCOUT), Y3.1
unnamed: C37.1, R13.1, U6.10 (RX)
unnamed: C38.1, R13.2, U6.9 (VMID)
RFANT1: C31.2, C36.1, J7.3 (SIG); also elsewhere on the board
RFANT2: C34.2, C35.2, J7.1 (GND), J7.2 (GND); also elsewhere on the board
SCK: U6.30 (SCK/P72); also elsewhere on the board

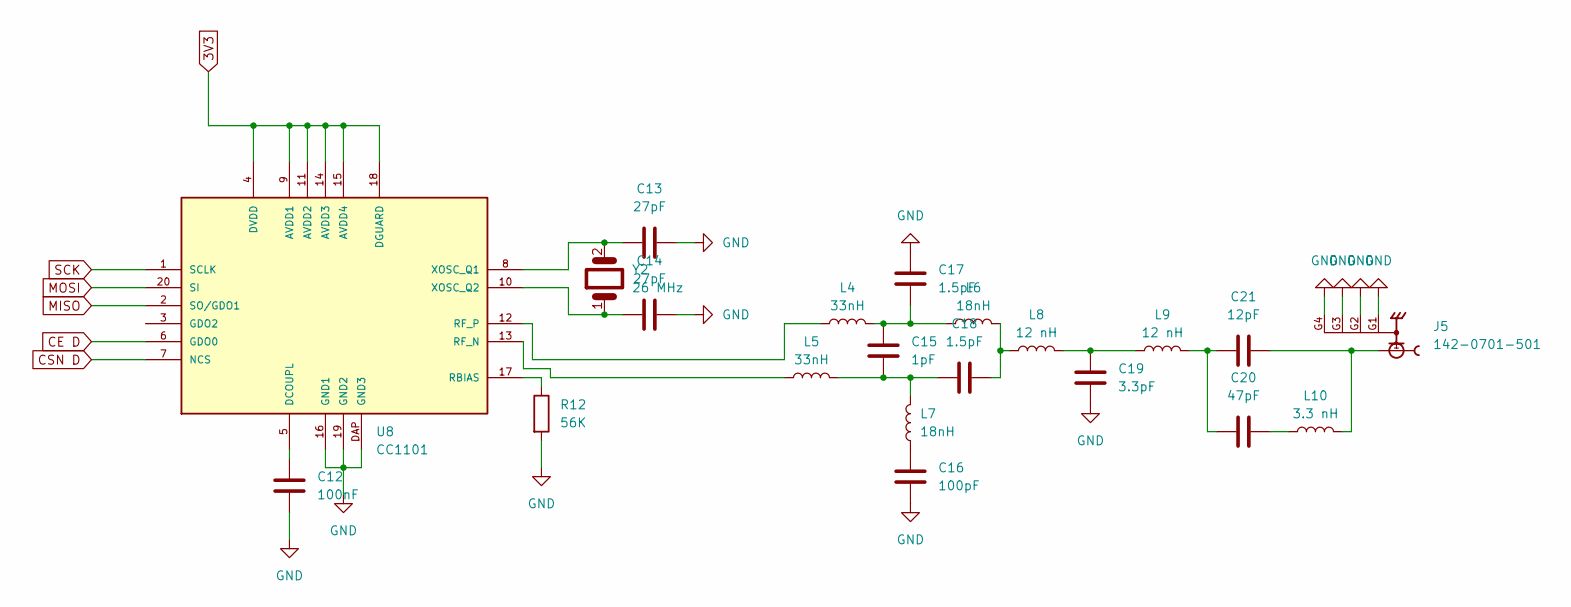
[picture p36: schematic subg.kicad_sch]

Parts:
C12: 100nF; C_0805_2012Metric
C13, C14: 27pF; C_0805_2012Metric
C15: 1pF; C_0805_2012Metric
C16: 100pF; C_0805_2012Metric
C17, C18: 1.5pF; C_0805_2012Metric
C19: 3.3pF; C_0805_2012Metric
C20: 47pF; C_0805_2012Metric
C21: 12pF; C_0805_2012Metric
J5: 142-0701-501; SMA_Molex_73251-1153_EdgeMount_Horizontal; PARTREV 7c
L4, L5: 33nH; L_0805_2012Metric
L6, L7: 18nH; L_0805_2012Metric
L8, L9: 12 nH; L_0805_2012Metric
L10: 3.3 nH; L_0805_2012Metric
R12: 56K; R_0805_2012Metric
U8: CC1101; QLP20
Y2: 26 MHz; Crystal_SMD_5032-2Pin_5.0x3.2mm_HandSoldering

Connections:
3V3: U8.4 (DVDD), U8.9 (AVDD1), U8.11 (AVDD2), U8.14 (AVDD3), U8.15 (AVDD4), U8.18 (DGUARD); also elsewhere on the board
CE D: U8.6 (GDO0); also elsewhere on the board
CSN D: U8.7 (NCS); also elsewhere on the board
GND: C12.1, C13.2, C14.2, C16.1, C17.2, C19.1, J5.G1, J5.G2, J5.G3, J5.G4, R12.2, U8.16 (GND1), U8.19 (GND2), U8.DAP (GND3); also elsewhere on the board
MISO: U8.2 (SO/GDO1); also elsewhere on the board
MOSI: U8.20 (SI); also elsewhere on the board
unnamed: C15.1, C18.2, L5.2, L7.2
unnamed: C15.2, C17.1, L4.2, L6.1
unnamed: C16.2, L7.1
unnamed: C18.1, L6.2, L8.1
unnamed: C19.2, L8.2, L9.1
unnamed: C20.1, C21.1, L9.2
unnamed: C20.2, L10.1
unnamed: C21.2, J5.1, L10.2
unnamed: C12.2, U8.5 (DCOUPL)
unnamed: R12.1, U8.17 (RBIAS)
unnamed: L5.1, U8.13 (RF_N)
unnamed: L4.1, U8.12 (RF_P)
unnamed: C13.1, U8.8 (XOSC_Q1), Y2.2
unnamed: C14.1, U8.10 (XOSC_Q2), Y2.1
SCK: U8.1 (SCLK); also elsewhere on the board

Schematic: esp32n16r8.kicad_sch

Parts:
R23, R24: 10K; R_0805_2012Metric
SW6: RESET; SW_SPST_EVQPE1
SW7: BOOT; SW_SPST_EVQPE1
U11: ESP32-S3-WROOM-1

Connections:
3V3: U11.2 (3V3); also elsewhere on the board
ANTSEL: U11.5 (IO5); also elsewhere on the board
ANTSEL1: U11.7 (IO7); also elsewhere on the board
BATT: U11.17 (IO9); also elsewhere on the board
BT1: U11.31 (IO38); also elsewhere on the board
BT2: U11.32 (IO39); also elsewhere on the board
BT3: U11.33 (IO40); also elsewhere on the board
BT4: U11.34 (IO41); also elsewhere on the board
CE B: U11.4 (IO4); also elsewhere on the board
CE D: U11.38 (IO2); also elsewhere on the board
CS A: U11.16 (IO46); also elsewhere on the board
CS C: U11.12 (IO8); also elsewhere on the board
CSN B: U11.25 (IO48); also elsewhere on the board
CSN D: U11.15 (IO3); also elsewhere on the board
CSN E: U11.39 (IO1); also elsewhere on the board
CSN F: U11.6 (IO6); also elsewhere on the board
DC A: U11.24 (IO47); also elsewhere on the board
GND: SW6.1, SW7.1, U11.1 (GND), U11.40 (GND), U11.41 (GND); also elsewhere on the board
IRLED: U11.35 (IO42); also elsewhere on the board
IRRECIVER: U11.26 (IO45); also elsewhere on the board
MISO: U11.10 (IO17); also elsewhere on the board
MOSI: U11.11 (IO18); also elsewhere on the board
unnamed: R23.1, SW7.2
unnamed: R24.1, SW6.2
unnamed: R23.2, U11.27 (IO0)
RST: R24.2, U11.3 (EN)
RST A: U11.18 (IO10); also elsewhere on the board
RX ESP: U11.36 (RXD0); also elsewhere on the board
SCK: U11.23 (IO21); also elsewhere on the board
TX ESP: U11.37 (TXD0); also elsewhere on the board

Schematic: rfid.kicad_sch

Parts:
C39, C40, C41, C42, C43, C44, C45, C46, C47, C48: 1uF; C_0805_2012Metric
L14, L15: 1 mH; L_0805_2012Metric
Q4, Q5: BC107; SOT-23_Handsoldering
R15, R16, R17, R18: 1K; R_0805_2012Metric
U10: MFRC522; QFN50P500X500X100-33N; PARTREV 3.9
Y4: 27.12 MHz; Crystal_SMD_5032-2Pin_5.0x3.2mm_HandSoldering

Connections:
3V3: U10.2 (PVDD), U10.3 (DVDD), U10.6 (~NRSTPD), U10.9 (SVDD), U10.12 (TVDD), U10.15 (AVDD); also elsewhere on the board
ANTSEL1: Q4.2 (B), Q5.2 (B); also elsewhere on the board
CSN F: U10.24 (SDA/NSS/RX); also elsewhere on the board
GND: C40.2, C41.2, C48.2, U10.4 (DVSS), U10.5 (PVSS), U10.10 (TVSS), U10.14 (TVSS), U10.18 (AVSS); also elsewhere on the board
MISO: U10.31 (D7/SCL/MISO/TX); also elsewhere on the board
MOSI: U10.30 (D6/ADR_0/MOSI/MX); also elsewhere on the board
unnamed: C39.2, R17.1
unnamed: C42.1, C45.1, L15.2
unnamed: C42.2, C47.1, R15.1
unnamed: C43.1, C44.2, L14.2
unnamed: C43.2, C46.2, R18.1
unnamed: C44.1, C45.2
unnamed: C46.1, C47.2
unnamed: Q4.3 (C), R17.2, U10.11 (TX1)
unnamed: L14.1, Q4.1 (E)
unnamed: Q5.3 (C), U10.13 (TX2)
unnamed: L15.1, Q5.1 (E)
unnamed: C41.1, U10.21 (OSCIN), Y4.2
unnamed: C48.1, U10.22 (OSCOUT), Y4.1
unnamed: C39.1, R16.1, U10.17 (RX)
unnamed: C40.1, R16.2, U10.16 (VMID)
RFANT1: R15.2; also elsewhere on the board
RFANT2: R18.2; also elsewhere on the board
SCK: U10.29 (D5/ADR_1/SCK/DTRQ); also elsewhere on the board

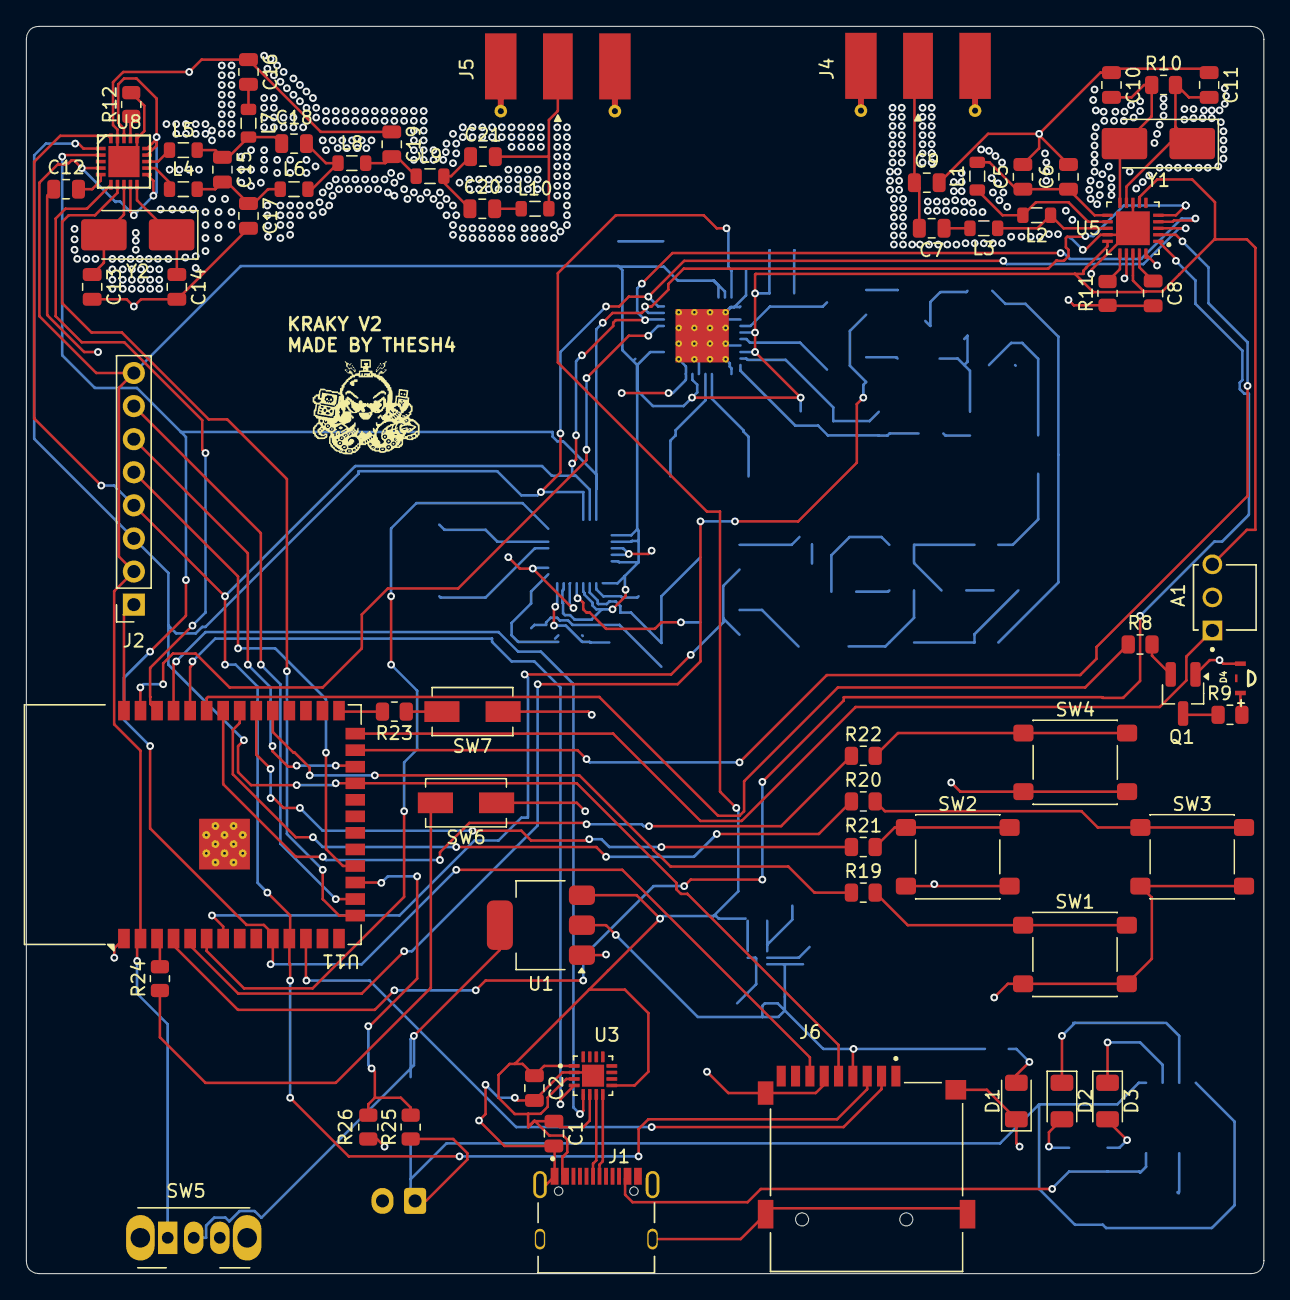
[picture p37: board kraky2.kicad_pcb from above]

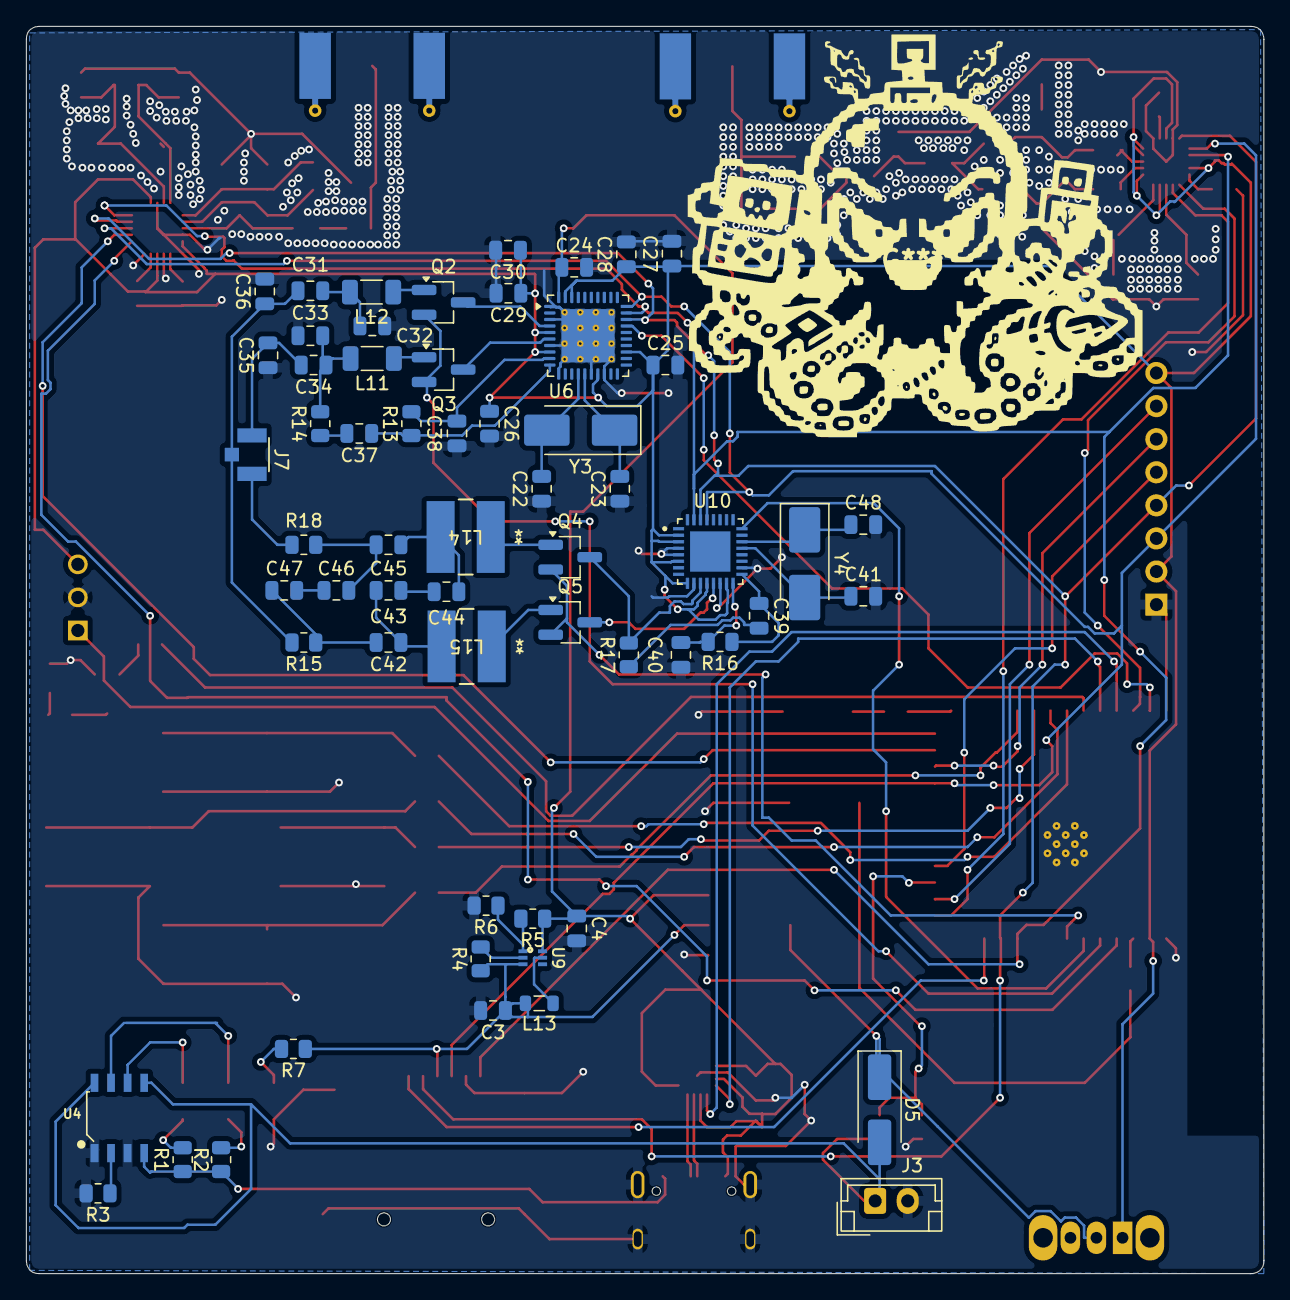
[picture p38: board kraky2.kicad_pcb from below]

Board: 2 copper layers, 95.0 x 95.8 mm, 127 parts (60 on the bottom side), 101 nets.

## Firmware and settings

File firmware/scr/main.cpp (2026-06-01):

/*
 * KRAKY2
 */

#include <Arduino.h>
#include <WiFi.h>
#include <Wire.h>
#include <SPI.h>

// ================= PIN =================

// Pulsanti
#define BTN_UP     41
#define BTN_DOWN   38
#define BTN_OK     40
#define BTN_BACK   39


// SPI (VSPI)
#define SPI_SCK    21
#define SPI_MISO   17
#define SPI_MOSI   18

// PN532 E
#include <Adafruit_PN532.h>
#define NFC_SS     1
#define NFC_ANTSEL 5
Adafruit_PN532 nfc(NFC_SS);

// LoRa D
#include <RadioLib.h>
#define LORA_CSN   3 //attivo se low
#define LORA_DIO0  2
CC1101 cc1101 = new Module(LORA_CSN, LORA_DIO0, RADIOLIB_NC, RADIOLIB_NC);

//IR
#include <IRremote.hpp>
#define IR_LED     42
#define IR_REC     45

//DISPLAY A ST7789
#include <Adafruit_GFX.h>
#include <Adafruit_ST7789.h>
#define DS_CS      46
#define DS_DC      47
Adafruit_ST7789 tft = Adafruit_ST7789(DS_CS, DS_DC, -1);

//WIFI B
#include <RF24.h>
#define WIFI_CSN   48 //attivo se low 
#define WIFI_CE    4
#include <WiFi.h>
RF24 nrf24(WIFI_CE, WIFI_CSN);
const byte address[6] = "00001";

//RFID F
#include <MFRC522.h>
#define RFID_CSN   6
#define RFID_ANTSEL 7
MFRC522 rfid(RFID_CSN, -1);

//MICRO SD SLOT C
#include <SD.h>
#define MSD_CS     8
//Battery 
#define BAT_PIN 9
//BLUETOOTH
#include <NimBLEDevice.h>
// ================= OGGETTI =================



// ================= MENU =================

struct Item {
  const char* name;
  int id;
  int parent;
};

Item menu[] = {
  {"WiFi",     0, -1},
  {"NFC",      1, -1},
  {"RFID",     2, -1},
  {"Sub-GHz", 3, -1},
  {"Bluetooth", 4, -1},
  {"IR", 5,-1},
  {"Settings", 6, -1},
  // WiFi
  {"Wifi Scan",     7, 0},
  {"Wifi Monitor",  8, 0},

  // NFC
  {"NFC Read",     9, 1},
  {"NFC Write",    10, 1},

  // RFID
  {"RFID Dump",     11, 2},
  {"RFID Clone",    12, 2},

  // subghz
  {"Sub-GHz Scan", 13, 3},
  {"Sub-GHz Jammer",  14, 3},

  //bluetooth
  {"BLE Scan", 15, 4},
  {"BLE Jammer", 16, 4},

  //IR
  {"IR Scan", 17, 5},
  {"IR Write", 18, 5},

  //settings
  {"Display", 19, 6},
  {"System",  20, 6},
};

int menuSize = sizeof(menu) / sizeof(menu[0]);

// ---------------- NAV STACK ----------------
int parentStack[10];
int selectedStack[10];
int level = 0;
int currentParent = -1;
int selected = 0;
int visibleItems[20];
int visibleCount = 0;
// ---------------- DRAW ----------------
void drawMenu() {
  tft.fillScreen(ST77XX_BLACK);
  tft.setTextSize(1);
  visibleCount = 0;
  int y = 20;

  for (int i = 0; i < menuSize; i++) {

    if (menu[i].parent == currentParent) {
      visibleItems[visibleCount] = i;
      visibleCount++;
      if (i == selected) {
        tft.setTextColor(ST77XX_BLACK, ST77XX_WHITE);
      } else {
        tft.setTextColor(ST77XX_WHITE);
      }

      tft.setCursor(10, y);
      tft.print(menu[i].name);
      y += 15;
    }
  }
}

// ---------------- FIND NEXT ----------------
int findNext(int start, int dir) {
  int i = start;

  while (true) {
    i += dir;
    if (i < 0) i = visibleCount - 1;
    if (i >= visibleCount) i = 0;

    return i;
  }
}


// ================= SETUP =================

void setup(){
  SPI.begin();
  //display
  tft.init(172, 320);
  tft.setRotation(1);
  tft.fillScreen(ST77XX_BLACK);
  //LoRa
  int state = cc1101.begin(868.0); // o 915.0
  //IR
  IrSender.begin(IR_LED); 
  IrReceiver.begin(IR_REC, ENABLE_LED_FEEDBACK);
  //WIFI
    //modalità trasmissione
  nrf24.begin();
  nrf24.openWritingPipe(address);
  nrf24.setPALevel(RF24_PA_LOW);
  nrf24.stopListening();
    //modalità ricezione
  nrf24.begin();
  nrf24.openReadingPipe(0, address);
  nrf24.setPALevel(RF24_PA_LOW);
  nrf24.startListening();
  //RFID
  rfid.PCD_Init();
  rfid.PCD_DumpVersionToSerial();
  //NFC
  nfc.begin();
  nfc.SAMConfig(); //modalità ascolto
  //Menù
  pinMode(BTN_UP, INPUT_PULLUP);
  pinMode(BTN_DOWN, INPUT_PULLUP);
  pinMode(BTN_OK, INPUT_PULLUP);
  pinMode(BTN_BACK, INPUT_PULLUP);
  drawMenu();
}

// ================= LOOP =================

void loop() {
  //Battery
    int raw = analogRead(BAT_PIN);
    float voltage = ((float)raw / 4095.0) * 3.3 * 2.0;
  //Menù
    // UP
    if (digitalRead(BTN_UP) == LOW) {
      selected = findNext(selected, -1);
      drawMenu();
      delay(150);
    }

    // DOWN
    if (digitalRead(BTN_DOWN) == LOW) {
      selected = findNext(selected, +1);
      drawMenu();
      delay(150);
    }

    // OK → entra nel submenu corretto
    if (digitalRead(BTN_OK) == LOW) {

      parentStack[level] = currentParent;
      selectedStack[level] = selected;
      level++;

      int index = visibleItems[selected];
      currentParent = index;   
      selected = 0;

      drawMenu();
      delay(200);
    }

    // BACK → torna di 1 livello
    if (digitalRead(BTN_BACK) == LOW) {

      if (level > 0) {
        level--;
        if (level > 0) {
        level--;
        currentParent = parentStack[level];
        selected = selectedStack[level];
      } else {
        currentParent = -1;
        selected = 0;
      }
        selected = selectedStack[level];
      }

      drawMenu();
      delay(200);
    }
}

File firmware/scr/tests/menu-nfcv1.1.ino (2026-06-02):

#include <Adafruit_GFX.h>
#include <Adafruit_ST7735.h>
#include <SPI.h>
#include <Adafruit_PN532.h>

// ---------------- DISPLAY TFT ----------------
#define TFT_CS   8
#define TFT_DC   9
#define TFT_RST  10

Adafruit_ST7735 tft = Adafruit_ST7735(TFT_CS, TFT_DC, TFT_RST);

// ---------------- BUTTONS ----------------
#define BTN_UP    2
#define BTN_DOWN  3
#define BTN_OK    4
#define BTN_BACK  5

// ---------------- PN532 NFC (SPI) ----------------
#define PN532_SS    6
#define PN532_IRQ   7

Adafruit_PN532 nfc(PN532_SS);

// Buffer per dati NFC
uint8_t nfcUid[7];
uint8_t uidLength;
bool nfcInitialized = false;

// ---------------- MENU STRUCT ----------------
struct Item {
  const char* name;
  int id;
  int parent;
};

Item menu[] = {
  {"NFC",        0, -1},
  {"Settings",   1, -1},
  // NFC submenu
  {"NFC Read",     2, 0},
  {"NFC Write",    3, 0},
  {"NFC Info",     4, 0},
  {"NFC Dump",     5, 0},
  {"Write Custom", 6, 0},
  // Settings
  {"Display",      7, 1},
  {"System",       8, 1},
};

int menuSize = sizeof(menu) / sizeof(menu[0]);

// ---------------- NAV ----------------
int parentStack[10];
int selectedStack[10];
int level = 0;
int currentParent = -1;
int selected = 0;

int visibleItems[20];
int visibleCount = 0;

// ---------------- NFC STATE ----------------
bool nfcModeActive = false;
String dataToWrite = "Hello NFC!";

// ---------------- DRAW MENU ----------------
void drawMenu() {
  tft.fillScreen(ST77XX_BLACK);
  tft.setTextSize(1);
  tft.setTextColor(ST77XX_WHITE);

  visibleCount = 0;
  int y = 20;

  for (int i = 0; i < menuSize; i++) {
    if (menu[i].parent == currentParent) {
      visibleItems[visibleCount] = i;
      visibleCount++;

      if (visibleCount - 1 == selected) {
        tft.setTextColor(ST77XX_BLACK, ST77XX_WHITE);
      } else {
        tft.setTextColor(ST77XX_WHITE, ST77XX_BLACK);
      }

      tft.setCursor(10, y);
      tft.print(menu[i].name);
      y += 15;
    }
  }
}

// ---------------- FIND NEXT ----------------
int findNext(int start, int dir) {
  int i = start;
  while (true) {
    i += dir;
    if (i < 0) i = visibleCount - 1;
    if (i >= visibleCount) i = 0;
    return i;
  }
}

// ---------------- AUTHENTICATE BLOCK ----------------
bool authenticateBlock(uint8_t block) {
  uint8_t keya[6] = { 0xFF, 0xFF, 0xFF, 0xFF, 0xFF, 0xFF };
  bool result = nfc.mifareclassic_AuthenticateBlock(nfcUid, uidLength, block, 0, keya);
  
  if (result) {
    Serial.print("✓ Blocco ");
    Serial.print(block);
    Serial.println(" autenticato");
  } else {
    Serial.print("✗ Errore autenticazione blocco ");
    Serial.println(block);
  }
  
  return result;
}

// ---------------- EXECUTE ACTION ----------------
void executeAction(int id) {
  nfcModeActive = true;
  
  switch(id) {
    case 2:
      nfcReadTag();
      break;
    case 3:
      nfcWriteTag();
      break;
    case 4:
      nfcShowInfo();
      break;
    case 5:
      nfcDumpMemory();
      break;
    case 6:
      nfcWriteCustomData();
      break;
    default:
      nfcModeActive = false;
      tft.fillScreen(ST77XX_BLACK);
      tft.setCursor(10, 50);
      tft.println("Funzione in");
      tft.println("sviluppo...");
      delay(1500);
      break;
  }
  
  if (!nfcModeActive) {
    drawMenu();
  }
}

// ---------------- WRITE CUSTOM (Mifare Classic specific) ----------------
void nfcWriteCustomData() {
  Serial.println("\n=== WRITE CUSTOM DATA (Mifare Classic) ===");
  
  tft.fillScreen(ST77XX_BLACK);
  tft.setTextColor(ST77XX_WHITE);
  tft.setCursor(5, 5);
  tft.println("WRITE CUSTOM DATA");
  tft.setCursor(5, 20);
  tft.println("Avvicina un tag...");
  tft.setCursor(5, 60);
  tft.println("Scrive in blocco 4:");
  tft.println("'luisllamas.es'");
  tft.setCursor(5, 140);
  tft.setTextColor(ST77XX_YELLOW);
  tft.println("BACK per uscire");
  
  while (nfcModeActive) {
    if (digitalRead(BTN_BACK) == LOW) {
      Serial.println("Uscita da Write Custom");
      nfcModeActive = false;
      delay(300);
      break;
    }
    
    Serial.println("In attesa di un tag...");
    bool success = nfc.readPassiveTargetID(PN532_MIFARE_ISO14443A, nfcUid, &uidLength, 200);
    
    if (success) {
      Serial.println("✓ Tag rilevato!");
      Serial.print("UID: ");
      for (uint8_t i = 0; i < uidLength; i++) {
        if (nfcUid[i] < 0x10) Serial.print("0");
        Serial.print(nfcUid[i], HEX);
        Serial.print(" ");
      }
      Serial.println();
      Serial.print("UID Length: ");
      Serial.println(uidLength);
      
      tft.fillScreen(ST77XX_BLACK);
      tft.setCursor(5, 5);
      tft.setTextColor(ST77XX_GREEN);
      tft.println("TAG RILEVATO!");
      tft.setTextColor(ST77XX_WHITE);
      
      tft.setCursor(5, 25);
      tft.print("UID: ");
      for (uint8_t i = 0; i < uidLength; i++) {
        if (nfcUid[i] < 0x10) tft.print("0");
        tft.print(nfcUid[i], HEX);
      }
      
      // Solo per Mifare Classic (UID length = 4)
      if (uidLength == 4) {
        tft.setCursor(5, 45);
        tft.println("Autenticazione...");
        Serial.println("Autenticazione blocco 4...");
        
        if (authenticateBlock(4)) {
          tft.setCursor(5, 65);
          tft.println("Autenticato blocco 4");
          
          uint8_t data[16];
          memcpy(data, (const uint8_t[]){ 'l', 'u', 'i', 's', 'l', 'l', 'a', 'm', 'a', 's', '.', 'e', 's', 0, 0, 0 }, sizeof data);
          
          Serial.println("Scrittura dati: luisllamas.es");
          tft.setCursor(5, 85);
          tft.println("Scrittura...");
          
          success = nfc.mifareclassic_WriteDataBlock(4, data);
          
          if (success) {
            Serial.println("✓ SCRITTURA COMPLETATA!");
            tft.setTextColor(ST77XX_GREEN);
            tft.setCursor(5, 105);
            tft.println("SCRITTURA OK!");
            tft.setTextColor(ST77XX_WHITE);
            tft.setCursor(5, 125);
            tft.print("Dati: luisllamas.es");
          } else {
            Serial.println("✗ ERRORE SCRITTURA!");
            tft.setTextColor(ST77XX_RED);
            tft.setCursor(5, 105);
            tft.println("ERRORE SCRITTURA!");
          }
        } else {
          Serial.println("✗ ERRORE AUTENTICAZIONE!");
          tft.setTextColor(ST77XX_RED);
          tft.setCursor(5, 65);
          tft.println("ERRORE AUTENTICAZIONE!");
        }
      } else {
        tft.setTextColor(ST77XX_RED);
        tft.setCursor(5, 45);
        tft.println("Solo Mifare Classic");
        tft.setCursor(5, 60);
        tft.println("UID 4 bytes");
        Serial.println("Questo tag non e' Mifare Classic (UID length != 4)");
      }
      
      delay(3000);
      
      tft.fillScreen(ST77XX_BLACK);
      tft.setTextColor(ST77XX_WHITE);
      tft.setCursor(5, 5);
      tft.println("WRITE CUSTOM DATA");
      tft.setCursor(5, 20);
      tft.println("Avvicina un tag...");
      tft.setCursor(5, 60);
      tft.println("Scrive in blocco 4:");
      tft.println("'luisllamas.es'");
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
